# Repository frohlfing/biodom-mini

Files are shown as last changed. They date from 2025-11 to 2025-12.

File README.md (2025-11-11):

# Projekt "Biodom Mini" – Ein Hightech-Gewächshaus

Das Ziel ist ein Mini-Gewächshaus für anspruchsvolle Pflanzen, das automatisch für ein tropisches Klima sorgt.

**Features:**

- Künstliche Sonne
- Konstante Temperatur
- Konstante Luftfeuchtigkeit
- Automatische Bewässerung
- Kamera (schießt regelmäßig Bilder für Zeitraffer-Video)
- Display (zeigt aktuelle Werte an)
- Webinterface (über WLAN erreichbar)

## Projektdokumentation

Eine detailliertere technische Dokumentation befindet sich in [Projektdokumentation.md](docs/Projektdokumentation.md).

## Lizenz

Dieses Projekt steht unter der [GPL-3.0-Lizenz](LICENSE).

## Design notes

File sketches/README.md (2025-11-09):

# Beschreibung Arduino Sketches 

In diesem Verzeichnis liegen Sketche für die [Arduino IDE](https://www.arduino.cc/en/software/), die ich für den ersten Funktionstest der Bauteile verwendet habe.

Im Unterordner `JpgToBmp` liegen die Sketche, die ich für die Entwicklung der gleichnamigen Funktion verwendet habe.

## 📦 Installation

Folgende Bibliotheken werden für diese Sketche benötigt und müssen mittels Library Manager installiert werden:

* [Arducam_mini 1.0.1 by Arducam](https://github.com/ArduCAM/Arducam_mini) für die ArduCAM Mini 2MP Plus (mit OV2640-Chip)
* [BH1750 1.3.0 by claws (Christofer Laws)](https://github.com/claws/BH1750) für den Lichtsensor GY-302 (BH1750)
* [DallasTemperature 4.0.5 by Miles Burton](https://github.com/milesburton/Arduino-Temperature-Control-Library) für den Bodentemperatursensor DS18B20
* [OneWire 2.3.8 by Paul Stoffregen](https://github.com/PaulStoffregen/OneWire) für den Bodentemperatursensor DS18B20 (setzt DallasTemperature voraus)
* [SimpleDHT 1.0.15 by Winlin](https://github.com/winlinvip/SimpleDHT) für den Raumtemperatur- und Luftfeuchtigkeitssensor AM2302
* [U8g2 2.35.30 by oliver](https://github.com/olikraus/u8g2) für das 1.3 Zoll OLED Display SSH1106
* [TJpg_Decoder 1.1.0 by Bodmer](https://github.com/Bodmer/TJpg_Decoder) für den JPGtoXBM-Konverter

(TODO: Diese nicht: [JPEGDEC 1.8.4 by Larry Bank](https://github.com/bitbank2/JPEGDEC) für den JPGtoXBM-Konverter)

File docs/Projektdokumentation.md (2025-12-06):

# Projekt "Biodom Mini" – Ein Hightech-Gewächshaus

* **Version:** 1.0.2
* **Datum:** 11.11.2025
* **Autor:** Frank Rohlfing

Das Ziel ist ein Mini-Gewächshaus für anspruchsvolle Pflanzen, das automatisch für ein tropisches Klima sorgt.

**Features:**

- Künstliche Sonne
- Konstante Temperatur
- Konstante Luftfeuchtigkeit
- Automatische Bewässerung
- Kamera (schießt ein Bild pro Tag für Zeitraffer-Video)
- Display (zeigt aktuelle Werte an)
- Webinterface (über WLAN erreichbar)

**Inhaltsverzeichnis**

* [Projekt "Biodom Mini" – Ein Hightech-Gewächshaus](#projekt-biodom-mini--ein-hightech-gewächshaus)
  * [1. Gehäuse](#1-gehäuse)
  * [2. Steuereinheit](#2-steuereinheit)
  * [3. Sensoren](#3-sensoren)
  * [4. Aktoren](#4-aktoren)
  * [5. Sonstige Peripheriegeräte](#5-sonstige-peripheriegeräte)
  * [6. Stromversorgung](#6-stromversorgung)
  * [7. Schaltplan](#7-schaltplan)
  * [8. Programmierung](#8-programmierung)

  * [Anhang](#anhang)

## 1. Gehäuse

### Gewächshaus 

AKERBÄR Gewächshaus 65, anthrazit

[Ikea](https://www.ikea.com/de/de/p/akerbaer-gewaechshaus-drinnen-draussen-anthrazit-20537175/)
29,99 €

Gewächshaus

Maße Gewächshaus

Maße: 65 x 22 (bzw. 13 oben) x 40 cm (B, T, H) 

### Blumenkasten 

Geli Blumenkasten Standard 60 cm

[Obi](https://www.obi.de/p/7331374/geli-blumenkasten-standard-ca-60-cm-anthrazit)
1,65 €

Blumenkasten

Maße: 60 x 18 x 13,7 cm (B, T, H)	

### Behälter für den Teich

Bedingungen: 
* Der Behälter muss eine grade Wand haben, um den Füllstandsensor anbringen zu können.
* Das Material darf aufgrund des Füllstandsensors nicht aus Metall sein (Glas, Kunststoff oder Keramik ist ok).
* Muss in den Blumenkasten passen (max. 12 cm tief, 13 cm hoch).

Ich habe diese Vase im Keller gefunden, passt perfekt:

* Material: Glas
* Außenmaße: 10 x 10 x 10 cm  
* Wandstärke: 4mm

### Bewässerungsset

Bewässerungsschlauch 4/6 mm (passend zur Wasserpumpe)

Bewässerungsset
Bewässerungsset

[Amazon](https://www.amazon.de/gp/product/B0DSP1KB8S)
7,98 €; "Einzelpreis": 3,99 €		

5 m Schlauch, 10 Tropf-Sprinkler, 2 Ventile, Verbinder (reicht locker für 2 Häuschen)

### Elektronik-Box

Kunststoffgehäuse 200 x 120 x 75 mm

Kunststoffgehäuse

[Amazon](https://www.amazon.de/dp/B0DJD3WC1V)
7,99 €

* IP65 (wasserdicht)

In das Gehäuse wird das Mainboard geschraubt. 

### Mainboard

Lochrasterplatine, 160 x 100 mm, blau 

Standard-Platine

[Amazon](https://www.amazon.de/gp/product/B081K7467B)
7,99 €

* Durchkontaktiert, runde Pads
* Rastermaß: 2,54 mm
* 1,6 mm dick

### Klinkenstecker und -Buchsen für die Sensoren (Kamera ausgenommen)

3.5 mm Stereo-Klinkenstecker und -Buchse 

Klinkenstecker und -Buchse

https://www.amazon.de/dp/B09TK2HNKD
6,79 € (10 Stück)

* Muss Stereo sein (3 Pins)!

4 Klinkenbuchsen werden benötigt für:
* Luft
* Bodentemperatur
* Bodenfeuchte
* Wasserstand

**Pinbelegung:**!



### Hohlstecker und -Buchen für die Aktoren und Stromversorgung

DC Power Jack Buchse und Stecker, 2.1 mm, 2 Polig 

Auch DC-Stecker und DC-Buchse genannt.

DC Buchse

[Amazon](https://www.amazon.de/dp/B07QNWSKN2)
7,49 € (12 Stück)

* Typ: 5.5 x 2.1 mm Buchse (passend zum 5.5x2.1 mm Holstecker des Netzteils)

7 Hohlstecker-Buchsen werden benötigt für:
* Lampe 1
* Lampe 2
* Heizer
* Dunst
* Pumpe
* Lüfter
* DC 12V

**Pinbelegung:**!



### Sonstiges Zubehör

**Stiftleisten und Buchsenleisten zum Einlöten auf die Platine** 

Auch unter "Pinheader" zu finden.

  Stift- und Buchenleisten

  [Amazon](https://www.amazon.de/dp/B0BZH6YZF8)
  10,99 €

**Kabelschlauch, selbstschließend**

Kabelschlauch

6 mm Durchmesser, 3 m: 
[Amazon](https://www.amazon.de/dp/B07FW5H57B)
7,99 €

13 mm Durchmesser, 3 m: 
[Amazon](https://www.amazon.de/dp/B07FW3GTXB)
7,99 €

**Abstandhalter Set**

Abstandhalter

[Amazon](https://www.amazon.de/dp/B0DCS5C7SN)
8,99 €

**Schraubklemmen Set**
Schraubklemmen
[Amazon](https://www.amazon.de/dp/B082ZNRQMJ)
8,99 €

## 2. Steuereinheit

### Mikrocontroller

ESP32-DevKitC V2

ESP32-DevKitC V2

[Amazon](https://www.amazon.de/dp/B074RGW2VQ)
10,99 €

[AZ-Delivery e-Book](https://cdn.shopify.com/s/files/1/1509/1638/files/AZ281_A_18-10_DE_B08BTWJGFX_e699c448-ffc6-4744-8b93-5c9f102d22b0.pdf),  
[Espressif Doku](https://docs.platformio.org/en/latest/boards/espressif32/esp32-c3-devkitc-02.html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),  
[Datasheet](https://cdn.shopify.com/s/files/1/1509/1638/files/ESP_-_32_NodeMCU_Developmentboard_Datenblatt_AZ-Delivery_Vertriebs_GmbH_10f68f6c-a9bb-49c6-a825-07979441739f.pdf)

* Micro-USB-Anschluss
* 38-Pin
* ESP32-WROOM-32-Chip
* CP2102

**Anmerkung:**

Das Modell mit UCD-C macht nur Probleme. Keins meiner UCB-C-Kabel hat funktioniert.

**Pinbelegung:**
<pre>  
                                       ┌────────────────┐
                           +3.3V Out ──┤ 3V3 ESP32  GND ├── GND
                                     ──┤ EN  DevKit G23 ├── GPIO23 SPI_MOSI ──► Kamera + SD-Karte
  Reserve analog./dgl. In ──► GPIO36 ──┤ SP  C V2   G22 ├── GPIO22 I2C_SCL  ──► Kamera + Display + Lichtstärke
       (frei analog./dgl. In) GPIO39 ──┤ SN         TXD ├── GPIO1  (UART0_TX)
    Bodenfeuchte (analog) ──► GPIO34 ──┤ G34        RXD ├── GPIO3  (UART0_RX)
              Wasserstand ──► GPIO35 ──┤ G35        G21 ├── GPIO21 I2C_SDA  ◄─► Kamera + Display + Lichtstärke
         Dunst Relais IN7 ◄── GPIO32 ──┤ G32        GND ├── GND
         Pumpe Relais IN6 ◄── GPIO33 ──┤ G33        G19 ├── GPIO19 SPI_MISO ◄── Kamera + SD-Karte
        Lüfter Relais IN5 ◄── GPIO25 ──┤ G25        G18 ├── GPIO18 SPI_CLK  ──► Kamera + SD-Karte
        Heizer Relais IN4 ◄── GPIO26 ──┤ G26         G5 ├── ──► LED
       Lampe-2 Relais IN3 ◄── GPIO27 ──┤ G27        G17 ├── GPIO17 SPI_CS   ──► Kamera
       Lampe-1 Relais IN2 ◄── GPIO14 ──┤ G14        G16 ├── GPIO16 SPI_CS   ──► SD-Karte
                        (frei, Boot) ──┤ G12         G4 ├── GPIO4           ◄─► Bodentemperatur (One-Wire)
                                 GND ──┤ GND         G0 ├── (frei, Boot)
  Luft (One-Wire-ähnlich) ◄─► GPIO13 ──┤ G13         G2 ├── (frei, Boot)
                                     ──┤ SD2        G15 ├── (frei, Boot)
                                     ──┤ SD3        SD1 ├──
                                     ──┤ CMD        SD0 ├──
                              +5V in ──┤ 5V  [USB]  CLK ├──
                                       └────────────────┘
</pre>

### Relaismodul

8-Kanal Relaismodul mit Optokoppler, 5V

[Amazon](https://www.amazon.de/dp/B07CT7SLYQ)
9,59 €

<pre>
         ┌────────────────┐
         │ 8 Relay    NC1 ├──  
         │ Module    Com1 ├──
         │            NO1 ├──
         │            NC2 ├──
         │           Com2 ├── +12V        GND ─O──(schwarz)── GND
         │            NO2 ├────────────────────O──(rot)────── A1: Lampe 1
   GND ──┤ GND        NC3 ├──   
       ─►┤ IN1       Com3 ├── +12V        GND ─O──(schwarz)── GND
GPIO14 ─►┤ IN2        NO3 ├────────────────────O──(rot)────── A2: Lampe 2
GPIO27 ─►┤ IN3        NC4 ├──
GPIO26 ─►┤ IN4       Com4 ├── +12V        GND ─O──(schwarz)── GND
GPIO25 ─►┤ IN5        NO4 ├────────────────────O──(rot)────── A3: Heizer
GPIO33 ─►┤ IN6        NC5 ├──
GPIO32 ──┤ IN7       Com5 ├── +12V        GND ─O──(schwarz)── GND
       ──┤ IN8        NO5 ├────────────────────O──(rot)────── A4: Lüfter
   +5V ──┤ VCC        NC6 ├──
         │           Com6 ├── +12V         GND ─O──(schwarz)── GND
         │            NO6 ├────────────────────O──(rot)────── A5: Pumpe  
         │            NC7 ├──
         │           Com7 ├── +5V        GND ─O──(schwarz)── GND
       ──┤ GND        NO7 ├────────────────────O──(rot)────── A6: Dunst
   Jum- ┌┤ VCC        NC8 ├──  
   per  └┤ JD-VCC    Com8 ├──
         │            NO8 ├──
         └────────────────┘
</pre>

**Anmerkung:**

Der Jumper zwischen VCC und JD-VCC muss gesteckt sein, da die Relais-Spulen auch von Steuerstromkreis versorgt werden sollen.

Um Induktionsspitzen beim Schalten abzufangen, wird ein Stützkondensator beim Spannungswandler eingesetzt (s. Kapitel6).

## 3. Sensoren

| Präfix | Name | Spezifikation | GPIO | Einkauf |
|---|---|---|---|---|
| S1 | Raumtemperatur- und Luftfeuchtigkeitssensor | AM2302 Module | GPIO13 | [Amazon](https://www.amazon.de/dp/B078SVZB1X) 8,49 € |
| S2 | Bodentemperatursensor | DS18B20 | GPIO4  | [Amazon](https://www.amazon.de/dp/B01MZG48OE) 8,29 € (2 Stück); Einzelpreis: 4,15 € |
| S3 | Bodenfeuchtigkeitssensor | Capacitive Soil Sensor v1.2 | GPIO34 | [Amazon](https://www.amazon.de/dp/B07HJ6N1S4) 6,46 € |
| S4 | Füllstandsensor | XKC-Y25-NPN | GPIO35 | [Amazon](https://www.amazon.de/dp/B0C1ZVZF2L) 10,19 € |
| S5 | Lichtsensor | GY-302 BH1750 | (I2C)  | [Amazon](https://www.amazon.de/dp/B07TKWNGZ4) 5,49 € |

### S1: AM2302
<pre>
┌────────────────┐
│ AM2302       - ├──(schwarz)─O─── GND 
│ Module     Out ├─►───(gelb)─O──► GPIO13
│              + ├──────(rot)─O─── +3.3V
└────────────────┘             
</pre>

### S2: DS18B20
<pre>
┌────────────────┐                   R1=4.7k
│ DS18B20    GND ├──(schwarz)─O────────────────── GND 
│           DATA ├─►───(gelb)─O─────┬───────────► GPIO4
│            VCC ├──────(rot)─O──┐  └─[ R1 ]─┐
└────────────────┘               └───────────┴─── +3.3V
</pre>

Pull-Up-Widerstand R1 = 4.7 kΩ

### S3: Capacitive Soil Sensor v1.2
<pre>
┌─────────────────┐
│ Capacitive  GND ├──(schwarz)─O─── GND 
│ Hygrometer  VCC ├──────(rot)─O─── +5V
│ v1.2       AOUT ├─►───(gelb)─O─►─ GPIO34
└─────────────────┘
</pre>

### S4: XKC-Y25-NPN

| Pin | Bezeichnung | Farbe am Sensor | Farbe am Klinkenstecker | Beschreibung |
|-----|---|---|---|---|
| 1 | VCC | braun | rot | Versorgung (5–12V) |  
| 2 | OUT | gelb | grün | Digitaler Ausgang | 
| 3 | GND | blau | weiß | GND |
| 4 | MODE | schwarz | - | Modus-Umschaltung (wird nicht benötigt)  | 

Eventuell sind Schwarz und Gelb vertauscht (OUT = Schwarz, MODE = Gelb)

<pre>
┌────────────────┐                     R2=10k 
│ XKC-Y25    VCC ├────(braun)─O───────────────── +5V   
│ -NPN       OUT ├─►───(gelb)─O─────┬──[ R2 ]─── +3.3V 
│            GND ├─────(blau)─O───┐ └─────────►─ GPIO35    
│           MODE ├──(schwarz)─O   └───────────── GND         
└────────────────┘    
</pre>

Pull-Up-Widerstand R2 = 10 kΩ

#### S5: BH1750
<pre>
┌────────────────┐
│ GY-302     VDD ├──────(rot)─O── +3.3V
│ BH1750     GND ├──(schwarz)─O── GND
│            SCL ├────(braun)─O─◄─ GPIO22
│            SDA ├───(orange)─O◄─► GPIO21 
│           ADDR ├─────(gelb)─O──
└────────────────┘
</pre>

## 4. Aktoren

| Präfix | Name | GPIO |
|---|---|---|
| A1 | Lampe 1 | GPIO14 | 
| A2 | Lampe 2 | GPIO27 |
| A3 | Heizer | GPIO26 |
| A4 | Lüfter | GPIO25 |
| A5 | Pumpe | GPIO33 |
| A6 | Vernebler | GPIO32 |

### A1, A2: Lampe

LED Grow Light 12V/60W, Vollspektrum, 4:1, IP65

LED-Streifen

[Amazon](https://www.amazon.de/gp/product/B076D3GCH4)
18,99 €

* 12V, 60W
* Rot:Blau = 4:1
* Vollspektrum
* IP65 (wasserdicht)
* 5m-Streifen (1 cm breit) mit 300 LEDs (SMD 5050)
* Hersteller: Tesfish

12V/60W = 5A (lt. Hersteller) -> Damit ist das Limit für ein Relais des Relais-Moduls erreicht. Daher teile ich den 
5m-Streifen in zwei Hälften, um die Last auf zwei Relais verteilen zu können. 
Außerdem könnte ich das Licht so in zwei Helligkeitsstufen schalten.  

**Aufteilung des LED-Streifens in 2 Lampen:**
<pre>
            O─▓▓▓▓▓▓▓▓▓▓▓▓▓▓▓▓▓▓▓▓▓▓▓▓▓▓▓▓▓▓▓─O┐
          ┌─O─░░░░░░░░░░░░░░░░░░░░░░░░░░░░░░░─O│┐
          │┌O─▓▓▓▓▓▓▓▓▓▓▓▓▓▓▓▓▓▓▓▓▓▓▓▓▓▓▓▓▓▓▓─O┘│
Lampe 1 O─┼─O─░░░░░░░░░░░░░░░  ░░░░░░░░░░░░░░─O─┘
Lampe 2 O─│┼O─▓▓▓▓▓▓▓▓▓▓▓▓▓▓▓  ▓▓▓▓▓▓▓▓▓▓▓▓▓▓─O┐
          └─O─░░░░░░░░░░░░░░░░░░░░░░░░░░░░░░░─O│┐
           └O─▓▓▓▓▓▓▓▓▓▓▓▓▓▓▓▓▓▓▓▓▓▓▓▓▓▓▓▓▓▓▓─O┘│
            O─░░░░░░░░░░░░░░░░░░░░░░░░░░░░░░░─O─┘
            <-------------- 60cm ------------->
</pre>

**UPDATE: Tatsächliche Leistung (Messwerte):**

* Leistung pro Streifenhälfte (2,5m): Spannung: 12 V, Strom: 2 A -> Reale Leistung: P = U * I = 12 V * 2 A = 24 Watt
* Leistung des gesamten Streifens (2 x 2,5m): Spannung: 11.9 V, Strom: 3.8 A -> Reale Gesamtleistung: P = 11.9 V * 3.8 A ≈ 45 Watt

Der gemessene Strom ist unter 4A, es würde 1 Relais reichen. (Sicherheitsmarge von 20 % ist ok). 
Aber dann kann ich nicht mehr zwei Helligkeitsstufen schalten. 

**Pinbelegung:**
<pre>
┌────────────────┐
│ LED Grow  +12V ├──────(rot)─O── Relais IN2
│ Light 1        │
│ 30W        GND ├──(schwarz)─O── GND
└────────────────┘
┌────────────────┐
│ LED Grow  +12V ├──────(rot)─O── Relais IN3
│ Light 2        │
│ 30W        GND ├──(schwarz)─O── GND
└────────────────┘
</pre>

**Passt die Lampe zum Gehäuse?**

**Ideale Lichtmenge (PPFD):**

* Die Lichtmenge wird in der Pflanzenwissenschaft in PPFD (Photosynthetic Photon Flux Density) gemessen. 
* Die Einheit ist µmol/m²/s. Der Wert gibt an, wie viele Photonen pro Sekunde auf einen Quadratmeter treffen. 
* Typische PPFD-Werte:
	* Cannabis:
		* Keimlinge/Stecklinge: 150 - 300 µmol/m²/s
		* Vegetatives Wachstum: 300 - 600 µmol/m²/s
		* Blütephase: 600 - 1.000 µmol/m²/s
	* Zitrone, Mango, Avocado: 
		* Wachstum (Jungpflanze): 300 - 500 µmol/m²/s
		* Fruchtbildung: > 700 µmol/m²/s.
	* Allround-Gewächshaus:
		* ≈ 400-600 µmol/m²/s

**Die Lichtmenge der Lampe:**

* **Leistung der Lampe:** Die Lampe wird mit 60W beworben. Laut [Kundenrezension](https://www.amazon.de/gp/customer-reviews/RP3TF4WHOI91K/ref=cm_cr_dp_d_rvw_ttl?ie=UTF8) leistet die Lampe nur 40 W. 

* **Effizienz der Lampe:** Die Effizienz einer Lampe wird in µmol/Joule angegeben. Sie sagt aus, wie viele Licht-Photonen (µmol) pro Wattsekunde (Joule) erzeugt werden.
Typische Werte für SMD 5050 Grow-LEDs, aus denen die Lampe besteht, liegen bei 1,5 bis 1,8 µmol/Joule. 

* **Pflanzenfläche:** Das AKERBÄR Gewächshaus hat unten eine Fläche von 0,60 x 0,2 m = 0,12 m².

* Jetzt können wir rechnen:

	* Gesamter Photonenfluss (PPF): Wie viele Photonen produziert die 40W-Lampe insgesamt pro Sekunde?
  
		PPF (µmol/s) = Leistung (Watt) * Effizienz (µmol/J)
	
		* Min: 40 W * 1.5 µmol/J = 60 µmol/s
		* Max: 40 W * 1.8 µmol/J = 72 µmol/s		

	* PPFD auf der Fläche - Jetzt verteilen wir diese Gesamtmenge an Photonen auf unsere Anbaufläche.
  
		PPFD (µmol/m²/s) = PPF (µmol/s) / Fläche (m²)

		* Min: 60 µmol/s / 0,12 m² = 500 µmol/m²/s
		* Max: 72 µmol/s / 0,12 m² = 600 µmol/m²/s

=> Die Lampe passt perfekt zum Gehäuse!

### A3: Heizer

Silikon-Heizmatte, 12V/12W, 60°C

Heizmatte

[Amazon](https://www.amazon.de/dp/B09VB1Q2G4)
7,19 €

* 12V, 12W
* bis 60°C
* 10 x 12 x 1,5cm

Der tatsächliche Strombedarf beträgt 930 mA (gemessen).

**Pinbelegung:**
<pre>
┌────────────────┐
│ Heating   +12V ├─────O── Relais IN4 
│ max. 60°C      │
│ 12W        GND ├─────O── GND
└────────────────┘
</pre>

### A4: Lüfter

PC-Lüfter, Silent, 12V, 8.5 CFM, 50 mm

Super Silent Fan

[Amazon](https://www.amazon.de/dp/B01HTN8XZE)
6,94 €;

* 12 V, 50 mA
* 50 x 50 mm
* 8,5 CFM
* 17,5 dB
* 3500 Umdrehungen pro Minute
 
**Pinout:**

| Pin | Bezeichnung | Farbe | Beschreibung |
|-----|---|---|---|
| 1 | +12V | rot | Versorgung |  
| 2 | GND | schwarz | GND |  
| 3 | RPM | gelb | Tachosignal  | 

**Anmerkung:**

Das gelbe Kabel mit der Bezeichnung "RPM" (Revolutions Per Minute) wird nicht benötigt. 
Es liefert ein "Tachosignal" (typischerweise 2 Pulse pro Umdrehung). Man könnte damit z.B. per Mikrocontroller prüfen, ob der Lüfter läuft oder blockiert ist.

**Pinbelegung:**
<pre>
┌────────────────┐
│ Fan       +12V ├──────(rot)─O── Relais IN5 
│                │
│ 0.6W       GND ├──(schwarz)─O── GND
└────────────────┘
</pre>

**Montage des Lüfters:**

[Montageanleitung des PC-Lüfters](https://m.media-amazon.com/images/I/91Py5fJkHrL.pdf)

Pflanzen verbrauchen CO₂ und geben Sauerstoff ab. Die "verbrauchte" und feuchte Luft steigt auf und sammelt sich im oberen Bereich des Gewächshauses.
Die Luft muss also von unten nach oben zirkulieren. 

Der Lüfter wird die Luft nach außen pusten und muss daher oben angebracht werden.

**Reicht die Leistung des Lüfters aus?**

Wie schnell der gewählte Lüfter die gesamte Luft im Gewächshaus austauschen kann. 
Ein guter Wert für ein kleines Gewächshaus liegt bei einer Luftaustauschrate von mindestens 1-mal pro Minute.

* Der Luftstrom der Lüfter wird in CFM (Cubic Feet per Minute) angegeben: 1 CFM ≈ 0,0283 m³/min

* Der ausgewählte PC-Lüfter pustet 8,5 CFM = 8.5 * 0,0283 m³/min = 0,24055 m³/min

* Das AKERBÄR Gewächshaus hat ein Volumen von 0,65 m * (0,22 m + 0,13 m)/2 * 0,40 m = 0,0455 m³.

* Die Luftaustauschrate ist somit 0,24055 m³/min / 0,0455 m³ ≈ **5,3-mal pro Minute**

=> Der Lüfter reicht völlig aus.

### A5: Pumpe

Mini 370 Membranpumpe, 12V

Wasserpumpe
Wasserpumpe

[Amazon](https://www.amazon.de/dp/B0DX5PVTBQ)
8,98 €

Wird mit 1 m Schlauch geliefert (5 mm innen).

* max. 300mA
* Saughöhe: 2m
* Durchflussmenge: 700ml

**Pinbelegung:**
<pre>
┌────────────────┐
│ Mini      +12V ├──────(rot)─O── Relais IN6 
│ Pump           │
│ 3.6W       GND ├──(schwarz)─O── GND
└────────────────┘
</pre>

### A6: Dunst

Ultraschall-Vernebler, 5V/5W

Vernebler
Vernebler Maße

[Amazon](https://www.amazon.de/gp/product/B0FM2FZD4Z)
12,49 €		

* 5V, 5W
* 1,4m Kabel
* 4,7 x 2,5 cm (B, H)
* Wassermangelschutz
* LED Farbwechsel

USB-Stecker abknipsen und Klinkenstecker anlöten.
Kabeladern:
* Braune = VCC
* Weiß = GND

**Pinbelegung:**
<pre>
┌────────────────┐
│ Mist       +5V ├──────(rot)─O── Relais IN7 
│ Maker       D- ├─────(weiß)─O── 
│ 5W          D+ ├─────(grün)─O── 
│            GND ├──(schwarz)─O── GND
└────────────────┘
</pre>

## 5. Sonstige Peripheriegeräte

| Präfix | Name | Spezifikation | GPIO | Einkauf |
|---|---|---|---|---|
| Z1 | Display | 1.3 Zoll OLED Display, SSH1106 | (I2C) | [Amazon](https://www.amazon.de/dp/B078J78R45) 8,49 € |
| Z2 | SD-Kartenleser | MicroSD SPI Kartenleser | CS: GPIO16 | [Amazon](https://www.amazon.de/gp/product/B0DQZFBCST) 4,29 € (3 Stück); Einzelpreis: 1,43 € |
| Z3 | Kamera | ArduCAM OV2640 Mini 2MP Plus | CS: GPIO17 | [BotLand](https://botland.de/kameras-fur-arduino-und-raspberry-pi/6556-arducam-mini-ov2640-2mpx-1600x1200px-60fps-spi-kameramodul-fur-arduino--5904422358242.html) 28,86 € |
| Z4 | LED | LED 3mm, rot | GPIO5 | |

### Z1: Display

<pre>
┌────────────────┐
│ 1.3″       VDD ├──────(rot)─O── +3.3V
│ OLED       GND ├──(schwarz)─O── GND
│ Display    SCK ├────(braun)─O─◄─ GPIO22
│ SSH1106    SDA ├───(orange)─O◄─► GPIO21 
└────────────────┘
</pre>

### Z2: SD-Kartenleser

<pre>
┌────────────────┐
│ MicroSD    GND ├───O─── GND
│ SPI       MISO ├───O─►─ GPIO19
│ Module     CLK ├───O─◄─ GPIO18
│           MOSI ├───O─◄─ GPIO23 
│             CS ├───O─◄─ GPIO16 
│            3v3 ├───O─── +3.3V
└────────────────┘
 </pre>

**Speicherkarte:**

SanDisk Ultra 32 GB microSDHC, Class 10, U1

Speicherkarte

[Amazon](https://www.amazon.de/dp/B08HVWJM8C)
7,78 €

* MicroSD (bis 2 GB) und MicroSDHC (4 bis 32 GB) funktionieren mit SPI.
* Geschwindigkeitsklasse: C10 ist Standard für Arduino/ESP32-Projekte (Schreibgeschwindigkeit: mind. 10 MB/s)
* Bus-Typ: UHS-I (U1 oder U3)
* Hersteller: SanDisk (Kingston oder Transcend wäre auch ok)

Die Karte sollte FAT32-formatiert sein.

**4 GB SD-Karte Class 4. vs. 32 GB HC Class 10**

Ich habe noch eine alte 4 GB SD-Karte Class 4. Wie lang reicht die Karte, wenn pro Stunde ein Bild geschossen wird? 
Wie schnell ist sie in der Praxis?

* 93 % einer SD-Karte sind durchschnittlich praktisch nutzbar.
* Die höchste Auflösung der ArduCAM-Kamera ist 1600 x 1200 Pixel. Die Bilder werden im JPEG-Format gespeichert. 
  Ich schätze 600 KB / Bild durchschnittlich.  

Es folgt:
* 4 GB: 4 GB * 0,93 * 1024 * 1024 / 600 KB = ≈ 6500 Bilder => 6500 / 24 ≈ **270 Tage**
* 32 GB: 32 GB * 0,93 * 1024 * 1024 / 600 KB = ≈ 52000 Bilder => 52000 / 24 / 365 ≈ **6 Jahre**

Theoretische Schreibgeschwindigkeit pro Bild:
* Class 4 (min. 4 MB/s): 0.6 MB / 4 MB/s = 150 ms. 
* Class 10 (min. 14 MB/s): 0.6 MB / 10 MB/s = 60 ms.

In der Realität ist der Prozess durch den ESP32 und die SPI-Kommunikation limitiert. 
Der gesamte Vorgang (Auslesen von der Kamera + Schreiben auf die Karte) wird vermutlich eher bei 1 bis 1,5 Sekunden liegen.

### Z3: Kamera

<pre>
┌────────────────┐
│ ArduCAM    SCL ├─◄───(orange)─O─── GPIO22
│ OV2640     SDA ├◄─►────(gelb)─O─── GPIO21
│ Mini       VCC ├───────(grün)─O─── +3.3V
│ 2MP Plus   GND ├───────(blau)─O─── GND
│            SCK ├─◄─────(lila)─O─── GPIO18
│           MISO ├─►─────(grau)─O─── GPIO19
│           MOSI ├─◄─────(weiß)─O─►─ GPIO23
│             CS ├─◄──(schwarz)─O─── GPIO17 
└────────────────┘        
 </pre>

### Z4: LED

Leuchtdiode 3mm, rot 

Nützlich zum Debuggen

Das längere Beinchen ist der Pluspol.

**Pinbelegung mit Vorwiderstand:**

<pre>
                      ↗↗     
GPIO5 ─▶───[ R2 ]─────▶├───── GND
            330 Ω    LED1
</pre>

## 6. Stromversorgung

| Präfix | Name | Spezifikation | Einkauf |
|---|---|---|---|
| P1 | Spannungswandler 12V zu 5V | Step-Down-Module XL4015 | [Amazon](https://www.amazon.de/dp/B07VQCXDTC) 9,99 € (3 Stück); Einzelpreis:	3,33 € |
| P2 | 12V Netzteil, 120W | 12V Steckernetzteil Adapter, 120W | [Amazon](https://www.amazon.de/gp/product/B0DBL4FV6C) 11,99 € 9,99 € (3 Stück); Einzelpreis:	3,33 € |

### P1: Spannungswandler 12V zu 5V

**Pinbelegung:**
<pre>
                   ┌────────────────┐
Netzteil DC +12V ──┤ IN+       OUT+ ├──┬──────────────────── ESP32 +5V
                   │  XL4015 Module │  └─⁺▌|─┐ C1: 470µF
             GND ──┤ IN.       OUT- ├────────┴────────────── GND
                   └────────────────┘
</pre>

**Stützkondensator C1**:

C1: Elko 470µF, 16V

Generell ist ein Stützkondensator zu empfehlen, dieser schützt vor Spannungseinbrüchen. 
Erst recht, wenn ein Relais eingesetzt wird, dessen JD-VCC-Jumper gesteckt ist.

Wird so nah wie möglich am Ausgang des Spannungswandlers gelötet.
Das längere Beinchen und der Pin ohne Markierung auf dem Gehäuse ist PLUS (+).
 
**Anmerkung:**

Die Ausgangsspannung muss auf **5 Volt** eingestellt werden!

### Netzteil

12V Steckernetzteil Adapter, 120W

**Benötigte Leistung / max. Stromaufnahme:**

5V-Komponenten (über Spannungswandler):

* ESP32-DevKitC C: 0,2 – 0,3A (je nach WLAN-Last)
* ArduCAM (SPI): ca. 0,1A (bei Kameraaufnahme)
* SD-Kartenleser (SPI): ca. 0,05A (nur bei Zugriff)
* OLED Display: ca. 0,02A (sehr gering)
* AM2302-Modul: ca. 0,002A (vernachlässigbar)
* DS18B20: ca. 0,002A (vernachlässigbar)
* Hygrometer-Modul: ca. 0,005–0,01 A (gering)
* XKC-Y25-NPN: ca. 0,1 A (bei Aktivierung)
* Ultraschall-Vernebler: ca. 1,0 A (Hauptlast auf 5V)

=> Summe worst case: ca. 1,6 A für 5V-Komponenten

Der Spannungswandler liefert bis zu 5A, also reichlich Reserve.

12V-Komponenten:

* LED Grow Light (5m, 60W): ca. 60W → 5,0A (Hauptlast, Dauerbetrieb)
* Heizmatte (12W):	12W → 1,0A (Dauerlast)
* 2x PC-Lüfter: ca. 0,1A gesamt
* Wasserpumpe Mini: max. 0,3A (Kurzzeitbetrieb)
* Relais-Modul (8-Kanal, 6 im Gebrauch): ca. 0,3A (50mA pro Relais)	(nur wenn alle Relais gleichzeitig anziehen)

=> Summe worst case: ca. 6,7 A für 12V-Komponenten

Max. Gesamtlast am Netzteil: **ca. 8,3 A**

Das 12V-Netzteil liefert 10 A, also sind ca. 1,7 A Reserve. Das ist knapp, aber im grünen Bereich.
 
## 7. Schaltplan

Den Sachaltplan habe ich mit KiCad 9.0 erstellt.



### Leiterplatten-Entwurf



## 8. Programmierung

### Entwicklungsumgebung / Technologie-Stack

* PlatformUI mit VS Code
* ArduinoIDE (nur für den erster schneller Funktionstest und Proof Of Concepts, die Sketches liegen im Verzeichnis `sketches`)
* ESP-Prog für das Debuggen (sofern nötig)
* Webinterface via Websocket (Frontend mit HTML, CSS, Vanilla JS, Single-Page)
* OTA-Upload (Over-The-Air) für das Produktivsystem

Mit der PlatformUI wird für jedes Bauteil eine lokale Bibliothek bereitgestellt und ausführlich dokumentiert.

Es wird auch jeweils eine Bibliothek für das Webinterface, für OTA und für den Zugriff auf die Sollwerte (als persistentes Dictionary o.ä.) bereitgestellt (um `main.cpp` möglichst schlank halten zu können). 

### Steuerungslogik

Die Steuerung soll dafür sorgen, dass ein gleichmäßiges Klima für die Pflanzen im Gewächshaus herrscht. 

Es wird folgende Steuerungslogik programmiert (in `main.cpp`):

*   **Lichtsteuerung (A1 und A2):**  
	* **Zur Tageszeit** werden die Lampen eingeschaltet, wenn das natürliche Tageslicht nicht ausreicht. 
	Dazu misst der Lichtsensor (S5) kontinuierlich das Tageslicht. 
	Ist das Tageslicht dunkler als der Schwellwert `LIGHT_LUX_THRESHOLD_DARK`, wird die Lampe eingeschaltet.
	Ist das Tageslicht heller als der Schwellwert `LIGHT_LUX_THRESHOLD_BRIGHT`, wird die Lampe ausgeschaltet.
    * **Außerhalb der Tageszeit** bleiben die Lampen aus.
    * Die Tageszeit ist definiert durch Einschaltzeit `LIGHT_ON_HOUR` und Ausschaltzeit `LIGHT_OFF_HOUR`.
    * Lampe 1 und Lampe 2 werden unabhängig voneinander gesteuert, d.h., für die Lampen können unterschiedliche Tageszeiten und Schwellwerte haben. 
  
* **Heizungssteuerung (A3):**  
Die Heizmatte wird aktiviert, wenn die **Bodentemperatur (S2)** unter den Zielwert `SOIL_TEMPERATUR_TARGET` fällt. Um ein ständiges An- und Ausschalten (Flattern) zu verhindern, wird eine Hysterese implementiert: Die Heizung schaltet sich erst wieder aus, wenn die Temperatur den Zielwert um 0.5 °C überschreitet.

*   **Lüftersteuerung (A4):**
Der Lüfter wird aktiviert, wenn die **Raumtemperatur (S1)** den Schwellwert `AIR_TEMPERATUR_THRESHOLD_HIGH` überschreitet. Er läuft dann für eine feste Dauer von `FAN_COOLDOWN_DURATION_MS`, um die warme und feuchte Luft effektiv abzuführen, und schaltet sich danach automatisch ab. Dies verhindert eine zu schnelle Austrocknung durch Dauerbetrieb.

*   **Bewässerungssteuerung (A5):** 
Die Wasserpumpe wird aktiviert, wenn die **Bodenfeuchte (S3)** unter den Zielwert `SOIL_MOISTURE_TARGET` fällt. Die Pumpe läuft dann für eine feste Dauer von `WATERING_DURATION_MS`, um eine definierte Menge Wasser abzugeben.  
**Ausnahme:** Die Pumpe wird niemals aktiviert, wenn der **Wasserstandsensor (S4)** meldet, dass der Wasserbehälter leer ist, um ein Trockenlaufen zu verhindern.

*   **Luftfeuchtesteuerung (A6):** Der Ultraschall-Vernebler (Dunst) wird eingeschaltet, wenn die **relative Luftfeuchtigkeit (S1)** unter den Zielwert `HUMIDITY_TARGET` sinkt. Auch hier sorgt eine Hysterese dafür, dass er sich erst wieder abschaltet, wenn die Luftfeuchtigkeit 5 % über dem Zielwert liegt. 
**Ausnahme:** Der Vernebler wird nur aktiviert, wenn der **Wasserstandsensor (S4)** ausreichend Wasser meldet.

*   **Wasserstands-Überwachung (S4):** Der Füllstandsensor wird kontinuierlich überwacht. Wenn er einen niedrigen Wasserstand (`!WATER_LEVEL_TRIGGERED`) meldet, wird auf dem Display eine bildschirmfüllende, blinkende Warnung angezeigt. Zusätzlich werden Pumpe (A5) und Vernebler (A6) deaktiviert.

*   **Kamerasteuerung (Z3):** In einem festen Intervall (z.B. alle 60 Minuten) wird ein Foto in hoher Auflösung (1600x1200) aufgenommen und auf der SD-Karte (Z2) gespeichert. Der Dateiname enthält einen Zeitstempel, um eine chronologische Sortierung zu ermöglichen (z.B. `img_20241017_143000.jpg`).

### Optimale Klimawerte

Eine Internet-Recherche über optimale Klimawerte für tropische Pflanzen ergab Folgendes:

*   **Temperatur:** 
    - Tropische Pflanzen, die oft aus Regenwäldern stammen, benötigen ein stabiles Klima mit hoher Luftfeuchtigkeit und gleichmäßig hohen Temperaturen. [1]

    - Für tropische Pflanzen sind Tagestemperaturen zwischen 20 °C und 30 °C ideal. [2]

    - Nachts sollten die Temperaturen nicht wesentlich unter 20 °C fallen. [3]

    - Die Bodentemperatur ist für die Wurzelaktivität ebenfalls entscheidend und sollte im warmen Bereich liegen. [2]

*   **Luftfeuchtigkeit:** 
    - Eine hohe relative Luftfeuchtigkeit ist für die meisten tropischen Pflanzen essenziell, um die Transpiration über die Blätter zu minimieren. Werte zwischen 60 % und 80 % sind optimal. [2]

*   **Bodenfeuchte:**  
    - Der Boden sollte konstant feucht, aber niemals durchnässt sein. [4]

    - Staunässe führt schnell zu Wurzelfäule und muss unbedingt vermieden werden. [5]

    - Der Boden sollte zwischen den Gießvorgängen leicht antrocknen können. [5]

*   **Lichtzyklus:** 
    - Ein Lichtzyklus von 12 bis 14 Stunden pro Tag simuliert die Bedingungen am Äquator und fördert ein gesundes vegetatives Wachstum. [6]

Quellen:

* [[1] hoklartherm.de](https://www.hoklartherm.de/ratgeber/tropische-pflanzen-gewaechshaus/)
* [[2] erlebnisgaertnerei.com](https://erlebnisgaertnerei.com/die-richtigen-temperaturen-im-gewaechshaus/)
* [[3] samen.de](https://samen.de/blog/temperaturmanagement-in-der-pflanzenanzucht-fuer-gesundes-pflanzenwachstum.html) 
* [[4] palmenstadl.de](https://palmenstadl.de/Die-richtige-Luftfeuchtigkeit-fuer-mediterrane-tropische-und-Wuestenpflanzen)  
* [[5] urban-jungle.store](https://www.urban-jungle.store/wie-giesse-ich-zimmerpflanzen-richtig/) 
* [[6] harmony-plants.com](https://www.harmony-plants.com/blogs/pflanzenmagazin/topf-und-bodenauswahl-fuer-tropische-pflanzen)

Damit lege ich folgende Sollwerte als Voreinstellung fest (diese können per Webinterface verändert werden): 

*   **`SOIL_TEMPERATUR_TARGET`**: `24.0` °C
*   **`SOIL_MOISTURE_TARGET`**: `50` % (Ein guter Mittelwert, der Staunässe vermeidet)
*   **`AIR_TEMPERATUR_THRESHOLD_HIGH`**: `28.0` °C (Ab hier wird es kritisch, Kühlung ist nötig)
*   **`HUMIDITY_TARGET`**: `70.0` %
*   **`LIGHT_ON_HOUR`**: `6` (6:00 Uhr)
*   **`LIGHT_OFF_HOUR`**: `20` (20:00 Uhr, ergibt einen 14-Stunden-Tag)

### Funktionsumfang

* **Bootvorgang:**  
  Nach dem Start wird eine Funktionsprüfung durchgeführt. Die Ergebnisse scrollen durch das Display. Wenn alles funktioniert, wird ein Splash-Screen (mein Portrait) für ein paar Sekunden angezeigt. Danach wird das Dashboard angezeigt. 

* **Dashboard:**  
  Das Dashboard teilt den Bildschirm in mehreren Bereichen auf. In jedem Bereich werden zusammenhängende Messwerte angezeigt. 

  Die Werte im Dashboard werden mit passenden Icons versehen:

  | Icon (XMB)     |                                                                | Verwendung                                                                       |
  |----------------|----------------------------------------------------------------|----------------------------------------------------------------------------------|
  | thermometer    | thermometer       | Icon für Raumtemperatur (S1)                                                     |
  | wet            | wet                       | Icon für Luftfeuchtigkeit (S1)                                                   |
  | engine_coolant | engine_coolant | Icon für Bodentemperatur (S2)                                                    |
  | moisture       | moisture             | Icon für Bodenfeuchte (S3)                                                       |
  | radiator       | radiator             | Heizung (A3) aktiviert (überlagert Icon für Bodentemperatur)                     |
  | air            | air                       | Lüfter (A4) aktiviert (überlagert Icons für Raumtemperatur und Luftfeuchtigkeit) |
  | rainy_weather  | rainy_weather   | Pumpe (A5) aktiviert (überlagert Icon für Bodenfeuchte)                          |
  | dry            | dry                       | Vernebler (A6) aktiviert (überlagert Icon für Bodenfeuchte)                      |
  
  Die ursprünglichen Icons habe ich bei [Icons8](https://icons8.com/icons/all--mono--size-small--technique-line) gefunden und in `data/icons` gespeichert (wo sie für das Webinterface verfügbar sind).  
  Diese unterliegen der [Universal Multimedia License von Icons8](https://intercom.help/icons8-7fb7577e8170/en/articles/5534926-universal-multimedia-license-agreement-for-icons8).
  Demnach dürfen sie verwendet werden, solange das Projekt nicht-kommerziell ist. 
  
  Die Icons habe ich mit GIMP in das XMB-Format konvertiert und im `Include`-Verzeichnis gespeichert, sodass sie auf dem OLED-Display angezeigt werden können.

* **Warnung bei niedrigem Wasserstand:**  
  Bevor der Wasserreservoir (Teich) trocken läuft, soll nicht das Dashboard, sondern eine blinkende Warnung auf dem Display angezeigt werden (gern mit Icon). Über das Handy soll der Benutzer auch gewarnt werden (per E-Mail?).

* **Bild aufnehmen:**  
  Nach einem festgelegten Intervall (alle x Stunden) wird ein Bild geschossen und auf der SD-Karte gespeichert. Direkt danach wird ein weiteres Bild mit niedrigster Auflösung erzeugt und auf dem Display für ein paar Sekunden angezeigt, um zu zeigen, dass ein Bild gespeichert wurde. 

* **Webinterface:**  
  Das Webinterface bietet folgende Funktionen für das Handy an:
  * Als Startseite wird das Dashboard angezeigt. 
  * Auf einer anderen Seite (bzw. Kartenreiter) können die Parameter für die Automatisierung verändert werden.
  *	Die Aktoren können manuell ein- und ausgeschaltet werden (wobei die Automatisierung dann außer Kraft gesetzt wird).
  * Außerdem gibt es eine Gallery mit den aufgenommenen Bilder und die Möglichkeit, diese als Zeitraffer-Video abzuspielen. 
  * Eine weitere Funktion zeigt Liniendiagramme mit den Messwerten.

## Anhang

### Verwendete ASCII-Schaltzeichen 

<pre>
Datenrichtung (Input, Output, Bidirektional)
◄── 
──► 
◄─►

Buchse
+ O──
- O──
            
IC, Sensor, Aktor
  ┌────────────────┐
──┤ In+       Out+ ├──
  │       U1       │
──┤ In-       Out- ├──
  └────────────────┘

Transistor   │ │ │
  ┌─────┐   ┌┴─┴─┴┐
  │ Q1  │   │C B E│
  │     │   │     │
  │C B E│   │ Q1  │   
  └┬─┬─┬┘   └─────┘
   │ │ │

Kreuzung:
─┼─

Widerstand
───[ R1 ]───

Kondensator
───┤├─── 
   C1

Elko
──⁺▌|───
+  C2  -  (das längere Beinchen ist der Pluspol)

Diode
───▶├───
+  D1  - (Ring)
   
LED
    ↗↗
───▶├───
+  LD1 -  (das längere Beinchen ist der Pluspol)
   
Fotodiode
   ↙↙
───▶├────
+  PD1  -

Lampe
───(╳)───
   HL1

</pre>

### Verwendete Präfixe im Schaltplan

* U: Mikrocontroller, ICs
* K: Relais (Kontaktor)
* S: Sensor
* A: Aktor
* Z: Sonstige Peripherie
* R: Widerstand (Resistor)
* C: Kondensator/Elko (Capacitor)
* P: Stromversorgung (Power Supply)
* Q: Transistor
* D: Diode
* H: Lampe
* J: Anschluss (Stiftleiste, Buchsenleiste, DC-Hohlbuchse,...)

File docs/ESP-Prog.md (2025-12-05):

# ESP-Prog

ESP-Prog ist ein Debugging-Tool von Espressif, basierend auf dem FT2232HL-Chip.

ESP-Prog  
[Benutzerhandbuch](https://docs.espressif.com/projects/esp-dev-kits/en/latest/other/esp-prog/user_guide.html)  
[H/W-Referenz](https://docs.espressif.com/projects/esp-dev-kits/en/latest/other/esp-prog/reference/reference-doc.html)  
[Erste Schritte mit PlatformIO](https://docs.platformio.org/en/latest/tutorials/espressif32/arduino_debugging_unit_testing.html)

## Schnittstellen

Der ESP-Prog stellt über ein einziges USB-Kabel zwei Schnittstellen bereit (per FTDI FT2232HL Chip):

* Interface 0 (JTAG-Schnittstelle): für Debugging und Upload via Standard-Debugging-Tool OpenOCD
* Interface 1 (UART-Schnittstelle): für Serielle Kommunikation (Serial Monitor/Plotter) und Upload via esptool.py

**Kommunikationswege:**

* Debug: PC -> USB -> ESP-Prog -> Interface 0 (JTAG) -> ESP32
* Serieller Monitor: ESP32 -> Interface 1 (UART) -> ESP-Prog -> USB -> PC

## Treiber

**Erforderliche Treiber unter Windows:**

* Für **Interface 0** muss der FTDI-Treiber durch einen WinUSB-Treiber ersetzt werden, 
weil OpenOCD nicht direkt mit dem FTDI-Treiber kommunizieren kann.

  Das geschieht so:

  1) [VCP-Treiber](https://ftdichip.com/drivers/vcp-drivers/) herunterladen und installieren
  VCP-Treiber
  2) Mit dem [Zadig-Tool](https://zadig.akeo.ie/) für "Dual RS232-HS (Interface 0)" den Treiber "FIDIBUS (v2.12.36.20)" mit "WinUSB (v6.1.7600.16385)" ersetzen. 
  Nachtrag: Der Upload läuft damit nicht zuverlässig. Hab nun "libusbK (v3.1.0.0)" installiert.
  Zadig
  3 ) USB-Kabel aus und wieder einstecken.

* Für **Interface 1** wird der benötigte FTDI-Treiber automatisch installiert, wenn der ESP-Prog zum ersten Mal angeschlossen wird.

Nach erfolgreicher Installation steht im Gerätemanager unter "USB-Geräte" der Eintrag "Dual RS232-HS" (für Interface 0, JTAG) und 
unter "Anschlüsse (COM & LPT)" der Eintrag "USB Serail Port (COM6)" (für Interface 1, UART).

Quelle: [BerryBase](https://blog.berrybase.de/esp32-debuggen-mit-espressif-esp-prog-platformio/)

## Buchsen

**Pinbelegung der PROG-Buchse:**

PROG-Schnittstelle

| Pin am ESP-Prog | | Farbe | Pin am ESP32 | 
|---|---|---|---|
| 1 EN | Reset | schwarz | EN | | 
| 2 VDD | VCC | rot | 3.3V oder nicht verbunden | 
| 3 TXD | UART Transmit | weiß | GPIO1 (TXD) |  
| 4 GND | GND | blau | GND |
| 5 RXD | UART Receive  | grau | GPIO3 (RXD) | 
| 6 IO0 | Strapping Pin | lila | GPIO0 | 

**Pinbelegung der JTAG-Buchse (für Debugging):**

JTAG-Schnittstelle

| Pin am ESP-Prog | | Farbe  | Pin am ESP32 | 
|---|---|---|---|
| 1 VDD | VCC | rot | 3.3V oder nicht verbunden | 
| 2 TMS | Test Mode State | braun  | GPIO14 | 
| 4 TCK | Test Clock | orange | GPIO13 |  
| 6 TDO | Test Data Out | gelb | GPIO15 | 
| 8 TDI | Test Data In | grün | GPIO12 | 
| 3,5,7,9 GND | GND | blau | GND | 

**Anschlusskabel:**

* Flachbandkabel (Ribbon Cable, meist 1.27mm oder 2.54mm Pitch)
* IDC-Stecker (2×3 und 2×5, Pfostenverbinder mit Schneidklemmen, auch Wannenstecker genannt)

Die Klemmen kann man mittels Schraubstock zusammenpressen.

## Stromversorgung

Der ESP-Prog wird über das USB-Kabel versorgt. Er kann den ESP32 mitversorgen, indem der 3.3V-Pin verbunden wird. 
Wenn aber eine andere Stromquelle für den ESP32 angeschlossen ist, **darf der 3.3V-Pin nicht verbunden werden!**

**Die PWR-SEL-Jumper müssen auf 3.3V gesetzt sein!**

Auf 5V dürfen keine der Jumper gesteckt werden, da sonst an einigen Pins mehr als 3.3 V liegen und der ESP32 darauf verschnupft reagieren könnte.

**Konfiguration:**

```
[env:esp32dev]
platform = espressif32
board = esp32dev
framework = arduino

; Debug- & Upload- Konfiguration
debug_tool = esp-prog
upload_protocol = esp-prog ; Upload über Inerface 0 (JTAG)
; upload_protocol = esptool ; Upload über Inerface 1 (UART)

; Serielle Monitor Konfiguration
monitor_port = COM6 ; siehe Gerätemanager unter "Anschlüsse (COM & LPT)" oder PlatformIO unter PIO Home -> Devices
monitor_speed = 115200

; Level 0=None, 1=Error, 2=Warn, 3=Info, 4=Debug, 5=Verbose
; siehe https://docs.platformio.org/en/latest/platforms/espressif32.html
build_flags = -DDEBUG_BAUDRATE=115200 ;-DCORE_DEBUG_LEVEL=1

; Enthält Einstellungen für den Build-Prozess während des Debuggens, wie z.B. O0 und ggdb, 
; um die Sichtbarkeit aller Variablen zu gewährleisten.
debug_build_flags = -O0 -g -ggdb

; Ermöglicht das Setzen von Breakpoints in der Setup-Funktion, was besonders nützlich ist, 
; um in der Initialisierungsphase zu debuggen.
debug_init_break = tbreak setup
```

Quellen:
[PlatformIO](https://docs.platformio.org/en/stable/plus/debug-tools/esp-prog.html),
[BerryBase](https://blog.berrybase.de/esp32-debuggen-mit-espressif-esp-prog-platformio/),
[Harald Kreuzer](https://www.haraldkreuzer.net/aktuelles/esp32-jtag-debugging-mit-platformio-und-nur-einer-usb-verbindung)

## Troubleshooting

OpenOCD testen:

```bash
& "C:\Users\frank\.platformio\packages\tool-openocd-esp32\bin\openocd.exe" -d2 -s "C:\Users\frank\.platformio\packages\tool-openocd-esp32\share\openocd\scripts" -f interface/ftdi/esp32_devkitj_v1.cfg -f board/esp-wroom-32.cfg -c "adapter speed 1000"
```

Reset‑Check mit OpenOCD:

```bash
& "C:\Users\frank\.platformio\packages\tool-openocd-esp32\bin\openocd.exe" `
  -d2 -s "C:\Users\frank\.platformio\packages\tool-openocd-esp32\share\openocd\scripts" `
  -f interface/ftdi/esp32_devkitj_v1.cfg -f board/esp-wroom-32.cfg `
  -c "adapter speed 1000" -c "init" -c "reset halt" -c "exit"
```

Flash-Kommando:

```bash
& "C:\Users\frank\.platformio\packages\tool-openocd-esp32\bin\openocd.exe" `
  -d2 -s "C:\Users\frank\.platformio\packages\tool-openocd-esp32\share\openocd\scripts" `
  -f interface/ftdi/esp32_devkitj_v1.cfg -f board/esp-wroom-32.cfg `
  -c "adapter speed 1000" `
  -c "init" `
  -c "reset halt" `
  -c "program_esp C:/Users/frank/Source/PlatformIO/biodom-mini/.pio/build/debug/firmware.bin 0x10000 verify" `
  -c "reset run" `
  -c "shutdown"
```  

Upload via PlatformIO-Befehl:  

```bash
pio run -e debug -t upload
```

ESP32 Chip-ID auslesen:

```bash
python -m esptool chip-id
```

Versionen einer Bibliothek auflisten:

```bash
pio lib show OneWire
```

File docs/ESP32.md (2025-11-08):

# ESP32

## GPIOs

Es wird die Standard-Pin-Belegung der Arduino IDE verwendet.

Folgende GPIOs stehen beim ESP32-DevKitC V2 zur Verfügung, wenn das WLAN-Modul aktiviert ist:

<pre>  
                            ┌────────────────┐
                +3.3V Out ──┤ 3V3 ESP32  GND ├── GND
                  (RESET) ──┤ EN  DevKit G23 ├── GPIO23 I/O SPI_MOSI
         ADC1-0 In GPIO36 ──┤ SP  C V2   G22 ├── GPIO22 I/O I2C_SCL
         ADC1-3 In GPIO39 ──┤ SN         TXD ├── GPIO1 (UART0_TX)
         ADC1-6 In GPIO34 ──┤ G34        RXD ├── GPIO3 (UART0_RX)
         ADC1-7 In GPIO35 ──┤ G35        G21 ├── GPIO21 I/O I2C_SDA
Touch-9 ADC1-4 I/O GPIO32 ──┤ G32        GND ├── GND
Touch-8 ADC1-5 I/O GPIO33 ──┤ G33        G19 ├── GPIO19 I/O SPI_MISO
          DAC1 I/O GPIO25 ──┤ G25        G18 ├── GPIO18 I/O SPI_CLK
          DAC2 I/O GPIO26 ──┤ G26         G5 ├── GPIO5 (Boot)
               I/O GPIO27 ──┤ G27        G17 ├── GPIO17 I/O UART2_TX
        (JTAG_TMS) GPIO14 ──┤ G14        G16 ├── GPIO16 I/O UART2_RX
  (Boot, JTAG_TDI) GPIO12 ──┤ G12         G4 ├── GPIO4 I/O
                      GND ──┤ GND         G0 ├── GPIO0 (Boot) 
        (JTAG_TCK) GPIO13 ──┤ G13         G2 ├── GPIO2 (Boot) 
            (Flash) GPIO9 ──┤ SD2        G15 ├── GPIO15 (Boot, JTAG_TDO) 
           (Flash) GPIO10 ──┤ SD3        SD1 ├── GPIO8 (Flash)
           (Flash) GPIO11 ──┤ CMD        SD0 ├── GPIO7 (Flash)
                   +5V In ──┤ 5V  [USB]  CLK ├── GPIO6 (Flash)
                            └────────────────┘
</pre>

**Legende:**

* **I/O:** Digitale Ein- und Ausgänge. Alle Ausgänge können auch PWM-Signale erzeugen.
* **In:**  Nur digitale Eingänge (GPIO 34 bis 36, 39). Nur für passive Sensoren geeignet.
* **ADC1 Analog-Digital-Wandler 1:**  Analoge Eingänge (12 Bit). ADC2 (GPIO 0, 2, 4, 12 bis 15 und 25 bis 27) ist mit dem WLAN-Modul nicht zuverlässig, bleibt daher im Diagramm unerwähnt.
* **DAC1, DAC2 (Digital-Analog-Wandler 1 und 2):** Analoge Ausgänge (8 Bit).
* **I2C:** I²C-Schnittstelle
* **SPI:** Virtual SPI-Schnittstelle. Hardware SPI wird selten gebraucht, bleibt daher im Diagramm unerwähnt.
* **Touch:** Interne kapazitive Touch-Sensoren. Die übrigen Touch-Sensoren werden aber durch das WLAN-Modul blockiert (GPIO 0, 2, 4, 12 bis 15 und 27).
* **(UART0), UART2:** Serielle Kommunikation. UART0 besser nicht verwenden. Die Pins sind intern mit dem USB-Wandler-Chip verdrahtet. UART2 ist unbenutzt. UART1 hat standardmäßig keine Pins zugewiesen (kann frei auf irgendwelche GPIOs gemappt werden).
* **(RESET):** Immer frei lassen!
* **(Flash):** GPIO 6 bis 11 sind intern mit dem Flash-Speicher verbunden. Diese Pins niemals verwenden!
* **(Boot):** GPIO 0, 2, 5, 12, 15 sind "Strapping-Pins". Besser nicht verwenden, denn der Bootvorgang wird hiermit beeinflusst. Könnten aber zur Not als digitale Ein- und Ausgänge verwenden werden (zu den Bedingungen siehe nachfolgende Tabelle). 
* **(JTAG):** GPIO 12, 13, 14, 15 können als digitale Ein- und Ausgänge verwendet werden, sofern kein Debugger (ESP-Prog) angeschlossen wird.

**Anmerkungen:**

* Der 5V-Pin versorgt den Onboard-Regler, der daraus 3.3V erzeugt. Toleranzbereich: 4.75 - 5.25V
* Max. Stromabgabe am 3.3V-Pin: 500mA
* Die GPIO Pins (General Purpose Input/Output Pins) arbeiten mit min. 2.3 bis max. 3.6 V, empfohlen werden 3.3V. 
	=> Das heißt: 
  * Sensoren mit 3.3V Betriebsspannung können direkt angeschlossen werden. 
  * Für Sensoren mit einem Ausgangspegel über 3.3V muss der Pegel z.B. durch einen Spannungsteiler (bestehend aus zwei Widerständen) auf 3.3V gedrückt werden!
* Laut Datenblatt (5.3 DC Characteristics) ist der Schwellwert für LOW/HIGH dieser:
  * Alles unter 0.825V wird sicher als LOW erkannt.
  * Alles über 2.475V wird sicher als HIGH erkannt.
* Der absolute Maximalstrom, der pro GPIO gezogen werden darf, beträgt 40 mA.
* Für die SPI-Schnittstelle ist GPIO 5 für CS (Chip Select; synonym für SS, Slave Select) vorgegeben. 
  Das ist ungünstig, denn beim Booten muss der Pin HIGH sein. 
  Daher besser, einen anderen digitalen Ausgang für CS zu wählen (und zwar pro Gerät einen).

### Strapping-Pins

| Pin | Funktion | Bedingung |
|---|---|---|
| GPIO 0  | Boot-Modus | Der Pin darf beim Booten nicht LOW sein. | 
| GPIO 2  | Boot-Modus & Logging | Der Pin darf beim Booten nicht LOW sein. | 
| GPIO 5  | Flash-Spannung | Der Pin darf beim Booten nicht HIGH sein.  | 
| GPIO 12 | Flash-Spannung | Der Pin darf beim Booten nicht HIGH sein.  | 
| GPIO 15 | Boot-Logging | Der Pin darf beim Booten nicht LOW sein. | 

## Hinweise zur Stromversorgung

### Schottky-Diode

Wenn das USB-Kabel und eine externe Spannungsversorgung an 5V-Pin angeschlossen sind, 
muss die externe Versorgung stabil sein. Wenn mehr als 5.2V am 5V-Pin anliegen, 
kann ein Rückstrom in das USB-Kabel fließen. Andersherum kann ein Rückstrom in das Netzteil fließen.  

Eine Schottky-Diode schützt das externe Netzteil vor einem Rückstrom:

<pre>
                 1N5817
Netzteil +5V ──────▶├────── ESP32_5V
                +  D1  - (Ring)
</pre>

1N5817:
* 20V Sperrspannung
* 1 A Dauerstrom
* ~0.3-0.5V Spannungsabfall

Allerdings liegt dann ca. 0.4V weniger am ESP32 an.

**Am besten einfach die externe Spannungsversorgung abklemmen, bevor das USB-Kabel eingesteckt wird!** 

### Spannungsteiler

Falls ein Sensor eine Betriebsspannung über 3.3 V hat, muss ein Spannungsteiler sicherstellen, 
dass der HIGH-Pegel nicht 3.3V überschreitet.

Beispiel - 5V-Sensor mit 5V als HIGH-Pegel:

<pre>
5V ──[ R1 ]─┬─[ R2 ]── GND
            │
          3.3V
</pre>

Teilverhältnis R2 / (R1 + R2) = 3.3 / 5 = 0.66

Faustregel: Der Gesamtwiderstand sollte im Bereich 10kΩ bis 100kΩ liegen.

Ich wähle 10 kΩ und 20 kΩ.
Die max. Ausgangsspannung ist somit 5V * (20kΩ / (20kΩ + 10kΩ) ≈ 3.33 V.

**Pinbelegung:**
<pre>
┌────────────────┐
│ V5-Sensor  GND ├──(schwarz)─O── GND 
│            VCC ├──────(rot)─O── +5V
│            OUT ├─►───(gelb)─O──[ R1 ]─┬─[ R2 ]── GND
└────────────────┘                      └────────► GPIO
                                    R1=10k ±1%  
                                    R2=20k ±1%
</pre>

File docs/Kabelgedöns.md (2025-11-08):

# Kabelgedöns

## AWG-Tabelle

| AWG | Durchmesser | Querschnitt  | Max. Dauerstrom | Drahttyp | Anwendung |
|-----|---|---|---|---|---|
| 22  | ca. 0,64 mm	| ca. 0,33 mm² | 2 - 5 A 	 | Litze (flexibel), z.B. Silikonkabel | Stromversorgung für Standard-Servos<br>• Kleinere bis mittlere Motoren<br>• Hauptstromversorgung für kleine Modelle<br>• Leistungsstarke LED-Beleuchtung |
| 23  | ca. 0,57 mm	| ca. 0,26 mm² | 1,5 - 4 A	 | Litze oder Massivdraht	 | Stromversorgung für Empfänger und Micro-Servos<br>• Längere Servo-Verlängerungskabel<br>• Weniger leistungsstarke Motoren | 
| 24  | ca. 0,51 mm	| ca. 0,20 mm² | 1 - 3 A	 | Litze (sehr verbreitet)	 | Signal- und Stromversorgung für Empfänger<br>• Stromversorgung für Micro-Servos<br>• Einzelne Power-LEDs<br>• Stromversorgung für Bordelektronik (z.B. Flugcontroller) | 
| 25  | ca. 0,45 mm	| ca. 0,16 mm² | 0,7 - 2 A	 | Litze	 | Signalübertragung (z.B. ESC, Sensoren)<br>• Stromversorgung für sehr kleine Servos (Sub-Micro)<br>• Interne Verdrahtung von Elektronikkomponenten | 
| 26  | ca. 0,40 mm	| ca. 0,13 mm² | 0,5 - 1.5 A | Litze (typ. für Jumperkabel)	 | Typische Signalleitungen (Servo, ESC)<br>• Stromversorgung für Sensoren (GPS, Gyro)<br>• Einzelne, kleine LEDs (z.B. Status-LEDs)<br>• Sehr leichte Modelle, wo jedes Gramm zählt | 

* Silikonkabel sind deutlich hitzebeständiger als normale PVC-Kabel und vertragen daher bei gleichem Querschnitt höhere Ströme.

## Kabel-, Stecker und Buchsensysteme

* Dupont Jumper Kabel
* IDC (Wannenstecker, Pfostenbuchsen)
* JST-XH (Zusatz "-XH" ist hier wichtig!)
* Molex

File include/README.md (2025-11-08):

Dieses Verzeichnis ist für Projekt-Headerdateien vorgesehen.

Eine Headerdatei ist eine Datei mit C-Deklarationen und Makrodefinitionen, die von mehreren Projektquelldateien gemeinsam genutzt werden. Man bindet sie mit der C-Präprozessor-Direktive `#include` ein:

```cpp
#include "header.h"

int main (void)

{
...
}
```

Weitere Informationen zur Verwendung von Headerdateien finden Sie in der offiziellen GCC-Dokumentation:
https://gcc.gnu.org/onlinedocs/cpp/Header-Files.html

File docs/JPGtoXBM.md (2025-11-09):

# Teilprojekt: JPGtoXBM

## Anforderung

Ich möchte mit der Kamera (ArduCAM Mini 2MP Plus OV2640) ein Jpg aufnehmen. Der ESP32 DevKitC V2 soll das Bild in ein Byte-Array umwandeln, so dass es auf dem 1.3 Zoll OLED Display SSH1106 angezeigt werden kann.
Das Display hat 128x64 Pixel, ist monochrom, 1 Bit pro Pixel.

### Grundsätzliche Konzeption: Die Daten-Pipeline

Die Herausforderung ist Transformation der Bilddaten. Diese ist rechenintensiv. Der ESP32 ist zwar schnell, aber man sollte keine Wunder erwarten. Die Konvertierung eines hochauflösenden Fotos wird einige Sekunden dauern. Für die Anzeige von Standbildern ist das aber völlig akzeptabel. 

Wir müssen eine Kette von Verarbeitungsschritten aufbauen, eine sogenannte Pipeline. Diese sieht konzeptionell so aus:

**JPG-Stream -> [ JPG-Dekompression ] -> [ Skalierung & Graustufen ] -> [ Dithering ] -> [ XBM-Formatierung ] -> XBM-Stream**

Die ArduCam oder die SD-Karte liefert den JPG-Datenstrom an die Pipeline.

1.  **Verarbeitungsschritt 1: JPG-Dekompression:**  
Die JPG-Daten sind komprimiert. Der erste Schritt muss sein, sie zu dekomprimieren, um an die rohen Pixelinformationen (Farbe für jeden einzelnen Bildpunkt) zu gelangen.
Das erledigt die Bibliothek [TJpg_Decoder by Bodmer](https://github.com/Bodmer/TJpg_Decoder).

(TODO: nicht diese: [JPEGDEC by Larry Bank](https://github.com/bitbank2/JPEGDEC))

Sie ist für genau diesen Zweck für zur Ausführung auf Mikrocontroller geschrieben. Um den verfügbaren RAM zu schonen, arbeitet die Bibliothek in kleinen Blöcken (sog. MCUs, oft 8x8 oder 16x16 Pixel). Sie dekomprimiert einen Block, und übergibt diesen an eine **Callback-Funktion**. In dieser Callback-Funktion führen wir dann unsere nachfolgenden Schritte (Skalierung, Dithering, Formatierung) durch, bevor der Decoder den nächsten Block liest.

2.  **Verarbeitungsschritt 2: Skalierung & Graustufen:**  
Das dekomprimierte Bild ist für das Display zu groß und farbig. Wir müssen es auf die Größe des Zieldisplays (128 x 64) herunterskalieren und die Farbinformationen in einen Graustufenwertumwandeln. 

3.  **Verarbeitungsschritt 3: Dithering (Monochrom-Umwandlung):**  
Jetzt haben wir ein kleines Graustufenbild. Da unser Display aber nur "An" (weiß) oder "Aus" (schwarz) kennt, müssen wir entscheiden, welcher Grauwert Schwarz und welcher weiß wird. Ein einfacher Schwellenwert würde zu hässlichen, detailarmen Bildern führen. Der **Dithering-Algorithmus von Floyd-Steinberg** ist hier die Lösung. Er macht folgendes:

    1.  Er nimmt den Grauwert des aktuellen Pixels (z.B. 100).
    2.  Er entscheidet: "Das ist näher an schwarz (0) als an weiß (255)". Er setzt das Pixel also auf Schwarz.
    3.  Er berechnet den "Fehler", den er gemacht hat: `100 - 0 = 100`.
    4.  Diesen Fehler verteilt er anteilig auf die benachbarten Pixel, die noch nicht verarbeitet wurden. Das nächste Pixel, das vielleicht einen Grauwert von 150 hatte, wird dadurch auf z.B. 180 angehoben und hat eine höhere Chance, weiß zu werden.  
    
    Ergebnis: Es entsteht eine Punktwolke, die für das menschliche Auge die Illusion von Grautönen erzeugt. Die Bildqualität ist um Welten besser.

4.  **Verarbeitungsschritt 4: XBM-Formatierung:**  
Das Ergebnis aus Schritt 3 muss nun in das XBM-Format (X BitMap) überführt werden (welches die U8g2-Bibliothek versteht). Das XBM hat diese Eigenschaften:
    - Monochrom: Es speichert nur 1-Bit-Informationen (schwarz/weiß).
    - C-Quellcode: Es ist kein binäres Dateiformat, sondern wird direkt als `C`-Quellcode gespeichert (`static const unsigned char ...`).
    - Feste Struktur: Jedes Byte repräsentiert 8 horizontale Pixel. Die Bits werden "rückwärts" gelesen, d.h. das niedrigstwertige Bit (LSB) ist das linkeste Pixel.

Das Ende der Pipeline ist ein XBM-Datenstrom, der von der `OLEDDisplaySH1106`-Klasse entgegengenommen und als Bild auf auf dem Bildschirm angezeigt werden kann.

### Proof Of Concept

Die Sketche hierzu sind unter `sketches/JPGtoXBM` abgelegt.

1.  **Proof Of Concept 1:** Wie wird ein im XBM-Format umgewandeltes JPG-Bild auf dem Display angezeigt? Ist die Qualität ausreichend? 
    *  Als Bild habe ich mein Portrait gewählt, es mit GIMP auf 128x64 Pixel verkleinert und im JPG-Format gespeichert:  
    JPG-Bild  
    Das JPG-Bild habe ich dann mit dem Tool [Online Image Converter to XBM](https://www.online-utility.org/image/convert/to/XBM) konvertiert:  
    XBM-Bild  
    Die resultierenden XBM-Daten habe ich als Headerdatei unter `frank_128x64_xbm.h` abgelegt. Einmal im `Include`-Verzeichnis (da ich sie auch als Splash-Screen verwenden möchte) und einmal in Ordner, in dem auch der Sketch liegt (damit die Arduino IDE diese einbinden kann).
    *  Um das XBM-Bild anzuzeigen, habe ich den Demo-Sketch `OLED_Display_SSH1106_Test.ino` genommen und alles bis auf das absolut Notwendigste entfernt. 

2.  **Proof Of Concept 2:** Wie kann auf dem ESP32 ein JPG-Bild in ein XBM-Bild umgewandelt werden? Reicht der RAM und wie lange dauert die  Verarbeitungszeit?  

    * In der Arduino IDE habe ich mittels Library Manager `https://github.com/bitbank2/JPEGDecoder` installiert.
    (TODO: nicht diese: `JPEGDEC 1.8.4 by Larry Bank`)
    * Das JPG-Bild aus PoC 1 (./assets/frank_128x64.jpg) habe ich nach folgender Anleitung von Meta-Angaben befreit:  
        1.  Öffne das Bild in GIMP.
        2.  Gehe zu `Datei -> Exportieren als...`.
        3.  Wähle als Dateityp `JPEG-Bild (*.jpg)` und gib ihm einen neuen Namen, z.B. `frank_clean_128x64.jpg` (im selben Ordner in dem auch der Sketch liegt).
        4.  Klicke auf `Exportieren`. Es öffnet sich ein Dialogfenster "Bild als JPEG exportieren".
        5.  Klappe den Bereich `Erweiterte Optionen` auf.
        6.  Entfernte die Haken bei folgenden Optionen:
            *   `EXIF-Daten speichern`
            *   `XMP-Daten speichern`
            *   `IPTC-Daten speichern`
            *   `Vorschaubild speichern`
            *   `Progressiv`
        7.  Klicke auf `Exportieren`.
    * Die Bytes des bereinigten JPG-Bildes habe ich dann in einem C-Array als Headerdatei `image_jpg.h` gespeichert (im selben Ordner wie der Sketch). Das hat das Python-Skript `convert.py` (auch im selben Ordner wie der Sketch) für mich erledigt. Statt dessen kann man auch das Online-Tool [File to hexadecimal converter](http://tomeko.net/online_tools/file_to_hex.php) nutzen - das Ergebnis ist das gleiche.

    🚧🚧🚧 TODO: Ab hier ist der PoC noch nicht umgesetzt! 🚧🚧🚧   
    Der Sketch baut auf dem Sketch von PoC 1 auf. Es lädt aber nicht die XBM-Daten, sondern die JPG-Daten, führt die Konvertierung durch und zeigt schließlich die resultierenden XBM-Daten wie im PoC 1 auf dem Display an.

3.  **Proof Of Concept 3:** Wie können die JPG-Daten von der Kamera bzw. von der SD-Karte als Datenstrom entgegengenommen werden? WIe kann der Datenstrom direkt an das Display weitergeleitet werden?

    Hier abstrahieren wir die Funktion, sodass sie nicht mehr von einer festen Datei abhängt, sondern jeden beliebigen Datenstrom verarbeiten kann.

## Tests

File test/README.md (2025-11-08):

# 🪲 Unit-Test

Dieses Verzeichnis ist für den PlatformIO Test Runner und Projekttests vorgesehen.

Unit-Testing ist eine Softwaretestmethode, bei der einzelne Einheiten des Quellcodes getestet werden, um festzustellen, ob sie einsatzfähig sind.

Die Unit-Tests können über das Labor-Icon der Aktivitätsleiste oder über die Kommandozeile gestartet werden:

```bash
pio test -e debug
```

## 📖 Siehe auch ...

[PlatformIO Unit-Testing](https://docs.platformio.org/en/latest/advanced/unit-testing/index.html)

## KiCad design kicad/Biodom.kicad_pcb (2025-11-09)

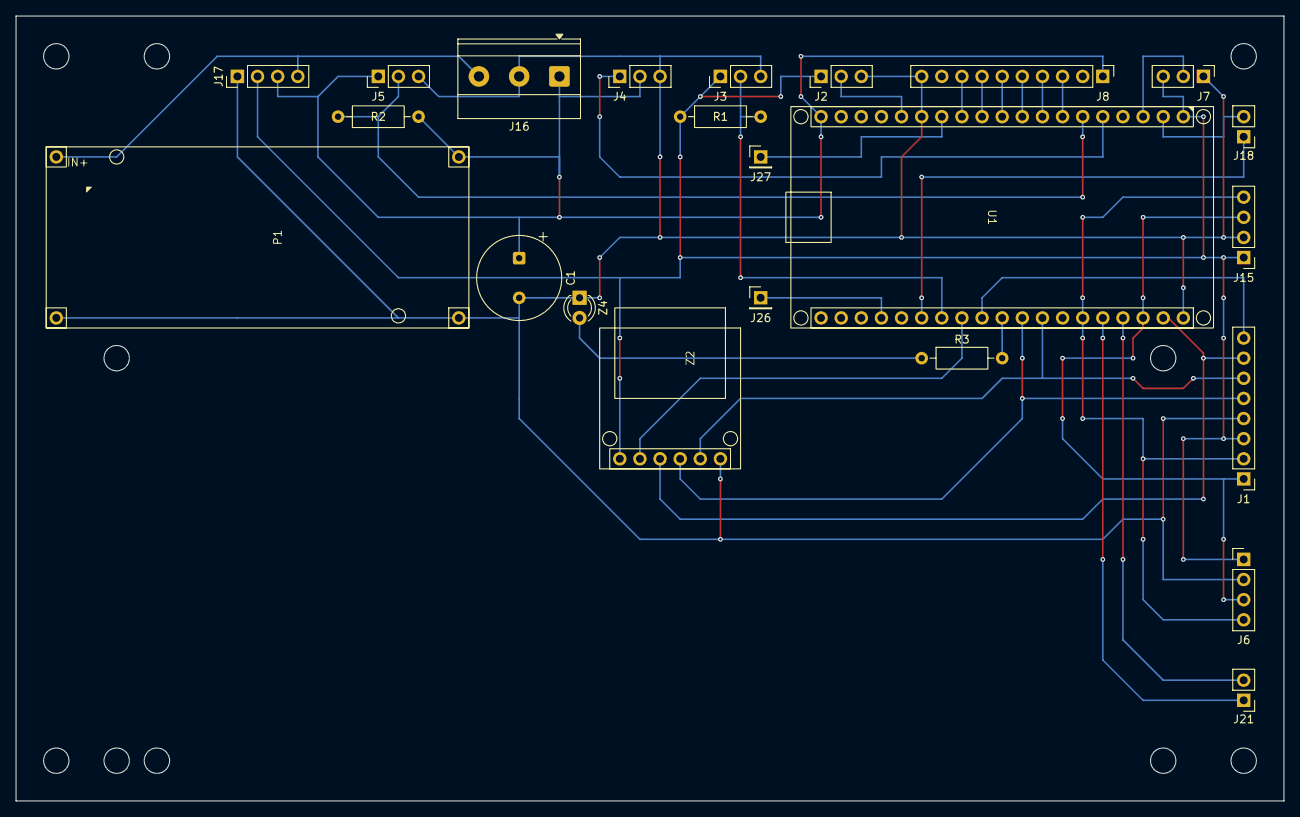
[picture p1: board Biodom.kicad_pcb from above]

Board: 2 copper layers, 160.0 x 99.1 mm, 23 parts (0 on the bottom side), 30 nets.

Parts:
C1: 470µF; CP_Radial_Tantal_D10.5mm_P5.00mm
J1: Kamera; PinHeader_1x08_P2.54mm_Vertical
J2: Luft; PinHeader_1x03_P2.54mm_Vertical
J3: Bodentemperatur; PinHeader_1x03_P2.54mm_Vertical
J4: Bodenfeuchte; PinHeader_1x03_P2.54mm_Vertical
J5: Wasserstand; PinHeader_1x03_P2.54mm_Vertical
J6: Lichtstärke; PinHeader_1x04_P2.54mm_Vertical
J7: Reserve S6; PinHeader_1x03_P2.54mm_Vertical
J8: Relais; PinHeader_1x10_P2.54mm_Vertical
J15: Display; PinHeader_1x04_P2.54mm_Vertical
J16: DC; TerminalBlock_Phoenix_MKDS-1,5-3-5.08_1x03_P5.08mm_Horizont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
J17: PWR; PinHeader_1x04_P2.54mm_Vertical
J18: RST; PinHeader_1x02_P2.54mm_Vertical
J21: UART; PinHeader_1x02_P2.54mm_Vertical
J26: TDO; PinHeader_1x01_P2.54mm_Vertical
J27: TDI; PinHeader_1x01_P2.54mm_Vertical
P1: Spannungsteiler; XL4015_Module_Socket
R1: 4,7kΩ; R_Axial_DIN0207_L6.3mm_D2.5mm_P10.16mm_Horizontal
R2: 10kΩ; R_Axial_DIN0207_L6.3mm_D2.5mm_P10.16mm_Horizontal
R3: 330Ω; R_Axial_DIN0207_L6.3mm_D2.5mm_P10.16mm_Horizontal
U1: ESP32; ESP32_DevKitC_V2_Socket
Z2: SD-Karte; MicroSD_SPI_Modul_Socket
Z4: LED; LED_D3.0mm

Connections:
+3V3: J1.3, J2.1, J3.1, J6.1, J7.3, J15.1, J17.2, R1.1, U1.1 (3V3), Z2.1 (3.3V)
+5V: C1.1, J4.2, J5.1, J8.1, J16.1, J17.3, P1.3 (OUT+), R2.1, U1.19 (5V)
+12V: J16.3, J17.4, P1.1 (IN+)
/EN: J18.2, U1.2 (EN)
/G0: J18.1, U1.25 (G0)
/G1: J21.2, U1.35 (TXD)
/G3: J21.1, U1.34 (RXD)
/G4: J3.2, R1.2, U1.26 (G4)
/G5: R3.2, U1.29 (G5)
/G12: J27.1, U1.13 (G12)
/G13: J2.2, U1.15 (G13)
/G14: J8.8, U1.12 (G14)
/G15: J26.1, U1.23 (G15)
/G16: U1.27 (G16), Z2.2 (CS)
/G17: J1.8, U1.28 (G17)
/G18: J1.5, U1.30 (G18), Z2.4 (CLK)
/G19: J1.6, U1.31 (G19), Z2.5 (MISO)
/G21: J1.2, J6.4, J15.4, U1.33 (G21)
/G22: J1.1, J6.3, J15.3, U1.36 (G22)
/G23: J1.7, U1.37 (G23), Z2.3 (MOSI)
/G25: J8.5, U1.9 (G25)
/G26: J8.6, U1.10 (G26)
/G27: J8.7, U1.11 (G27)
/G32: J8.3, U1.7 (G32)
/G33: J8.4, U1.8 (G33)
/G34: J4.1, U1.5 (G34)
/G35: J5.2, R2.2, U1.6 (G35)
/G36: J7.2, U1.3 (SP)
/LED+: R3.1, Z4.2 (A)
GND: C1.2, J1.4, J2.3, J3.3, J4.3, J5.3, J6.2, J7.1, J8.10, J15.2, J16.2, J17.1, P1.2 (IN-), P1.4 (OUT-), U1.14 (GND), U1.38 (GND), Z2.6 (GND), Z4.1 (K)

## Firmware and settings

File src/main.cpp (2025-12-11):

/**
 * @file main.cpp
 * @brief Hauptprogramm für das "Biodom Mini" Projekt.
 *
 * Diese Datei enthält die Hauptlogik zur Steuerung des Gewächshauses.
 * Sie initialisiert alle Sensoren und Aktoren, liest periodisch Messwerte aus,
 * wendet die Steuerungslogik an und aktualisiert die Anzeige.
 *
 * @version 1.0.9
 * @date 11.12.2025
 * @author Frank Rohlfing
 *
 * Derzeit können die Kameraeinstellungen noch nicht gespeichert werden.
 */

#include <Arduino.h>
#include <WiFi.h>
// #include <ArduinoOTA.h>
#include <ArduinoJson.h>
#include <LittleFS.h>
#include <SD.h>
#include <Wire.h>

// -- Einbinden der Konfiguration und der lokalen Bibliotheken --
#include "config.h"
#include "secrets.h"
#include "settings.h"
#include "SettingsManager.h"
#include "WebUI.h"
#include "ArduCamOV2640.h"
#include "LED.h"
#include "MicroSDCard.h"
#include "OLEDDisplaySH1106.h"
#include "OTA.h"
#include "Relay.h"
#include "SensorAM2302.h"
#include "SensorBH1750.h"
#include "SensorCapacitiveSoil.h"
#include "SensorDS18B20.h"
#include "SensorXKCY25NPN.h"

// Splash Screen
#include "xbm/frank_128x64_xbm.h" // definiert das C-Array frank_128x64_bits[]

// Icons für das Dashboard
#include "xbm/thermometer_16x16_xbm.h"    // Icon für Raumtemperatur (S1)
#include "xbm/wet_16x16_xbm.h"            // Icon für Luftfeuchtigkeit (S1)
#include "xbm/engine_coolant_16x16_xbm.h" // Icon für Bodentemperatur (S2)
#include "xbm/moisture_16x16_xbm.h"       // Icon für Bodenfeuchte (S3)

// Icons, wenn Aktoren aktiv sind
#include "xbm/radiator_16x16_xbm.h"      // Heizung (A3) aktiviert (überlagert Icon für Bodentemperatur)
#include "xbm/air_16x16_xbm.h"           // Lüfter (A4) aktiviert (überlagert Icons für Raumtemperatur und Luftfeuchtigkeit)
#include "xbm/rainy_weather_16x16_xbm.h" // Pumpe (A5) aktiviert (überlagert Icon für Bodenfeuchte)
#include "xbm/dry_16x16_xbm.h"           // Vernebler (A6) aktiviert (überlagert Icon für Luftfeuchtigkeit)

// === Globale Objektinstanzen ===

// --- Einstellungen ---
SettingsManager settingsManager;

// --- Webinterface ---
WebUI webInterface;

OTA ota(HOSTNAME, OTA_PASSWORD);

// --- Sensoren ---
SensorAM2302 airSensor(PIN_AIR_SENSOR); // Raumtemperatur- und Luftfeuchtigkeitssensormodul AM2302 (S1)
SensorDS18B20 soilTempSensor(PIN_SOIL_TEMPERATUR_SENSOR); // Bodentemperatursensor DS18B20 (S2)
SensorCapacitiveSoil soilMoistureSensor(PIN_SOIL_MOISTURE_SENSOR, SOIL_MOISTURE_ADC_DRY, SOIL_MOISTURE_ADC_WET); // Kapazitiver Bodenfeuchtigkeitssensor v1.2 (S3)
SensorXKCY25NPN waterLevelSensor(PIN_WATER_LEVEL_SENSOR); // Berührungsloser Füllstandsensor XKC-Y25-NPN (S4)
SensorBH1750 lightSensor; // Lichtsensor GY-302 BH1750 (S5)

// --- Aktoren (Relais) ---
// Die Relais sind active-low, d.h. LOW schaltet sie ein.
Relay lamp1Relay(PIN_LAMP1_RELAY);    // Lampe 1 (A1)
Relay lamp2Relay(PIN_LAMP2_RELAY);    // Lampe 2 (A2)
Relay heaterRelay(PIN_HEATER_RELAY);  // Heizer (A3)
Relay fanRelay(PIN_FAN_RELAY);        // Lüfter (A4)
Relay pumpRelay(PIN_PUMP_RELAY);      // Wasserpumpe (A5)
Relay misterRelay(PIN_MISTER_RELAY);  // Vernebler (A6)

// --- Sonstige Peripherie ---
OLEDDisplaySH1106 display;            // 1.3 Zoll OLED Display, SSH1106 (Z1)
MicroSDCard sdCard(PIN_SPI_SD_CS);    // MicroSD SPI Kartenleser (Z2)
ArduCamOV2640 camera(PIN_SPI_CAMERA_CS); // ArduCAM OV2640 Mini 2MP Plus (Z3)
LED debugLed(PIN_DEBUG_LED);          // LED (Z4)

// === Globale Variablen zur Zustandsspeicherung ===

// --- Sensorwerte ---
// Diese Variablen speichern die zuletzt gemessenen Werte, um sie im Programmablauf zu verwenden.
// Sie werden mit "Not a Number" (NAN) oder -1 initialisiert, um anzuzeigen, dass noch keine gültige Messung stattgefunden hat.
float currentAirTemp = NAN;         // Aktuelle Raumtemperatur in °C (S1)
float currentHumidity = NAN;        // Aktuelle Luftfeuchtigkeit in % (S1)
float currentSoilTemp = NAN;        // Aktuelle Bodentemperatur in °C (S2)
int currentSoilMoisture = -1;       // Aktuelle Bodenfeuchte in % (S3), -1 bedeutet "ungültig/nicht gemessen"
bool isWaterLevelOk = false;        // Zustand des Wasserfüllstands (S4), startet mit 'false' (kein Wasser), bis erste Messung erfolgt.
float currentLightLux = NAN;        // Aktuelle Lichtstärke in Lux (S5)

// --- Zeitsteuerung für nicht-blockierende Operationen ---
// Diese Variablen speichern den Zeitpunkt (in Millisekunden seit Start) der letzten Ausführung,
// um Aktionen in festen Intervallen ohne blockierende delay()-Aufrufe durchzuführen.
unsigned long lastSensorRead = 0;     // Zeitpunkt der letzten Sensormessung
unsigned long lastDisplayUpdate = 0;  // Zeitpunkt der letzten Display-Aktualisierung
unsigned long lastCameraCapture = 0;  // Zeitpunkt der letzten Kameraaufnahme
unsigned long lastBroadcastTime = 0;  // Zeitpunkt der letzten Broadcast-Nachricht

// === Funktionsprototypen ===

void printFileSystemInfo();
bool readSensors();
void controlActors();
void controlCamera();
void updateDisplay();
void applyCameraSettings();
bool capture();
JsonObject getStateAsJson(JsonDocument& doc);
void broadcastState();
void broadcastSettings();
void handleWSClientConnect(AsyncWebSocketClient* client);
void handleWSMessage(AsyncWebSocketClient* client, const String& msg);
/**
 * Hält das Programm an.
 *
 * Gibt vor dem Halt eine Meldung und optional weitere Details aus.
 * Zusätzlich wird die Debug-LED eingeschaltet.
 * @param message Die Fehlermeldung, die auf dem Display und seriell ausgegeben wird.
 * @param detail Details zur Fehlermeldung (optional).
 */
void halt(const char* message, const char* detail = "") {
    Serial.println(message);
    display.addLogLine(message);
    if (strlen(detail) > 0) {
        Serial.println(detail);
        display.addLogLine(detail);
    }
    Serial.println(F("System angehalten"));
    display.addLogLine(F("System angehalten"));

    // LED dauerhaft einschalten, um den Halt zu signalisieren.
    debugLed.on();

    delay(1000);
    ESP.restart();

    // // Endlosschleife, um das Programm anzuhalten
    // while (true) {
    //     delay(100); // Prozessor entlasten
    // }
}

/**
 * Gibt den Logeintrag aus.
 *
 * Es wird etwas gewartet, damit der Eintrag auch auf dem Display gelesen werden kann,
 * bevor eventuell der nächste Eintrag angezeigt wird.
 */
void log(const char* message) {
    Serial.println(message);
    display.addLogLine(message);
    delay(LOG_DELAY);
}

/*
Symptom:
Nach einem "Soft Reset" (Software-Upload, OTA oder Reset-Knopf) bleibt die Bootsequenz bei "SD-Karte ok" hängen.
Wenn die Stromversorgung kurz aus und wieder eingeschaltet wird, startet der ESP ohne Probleme.

Die Ursache:
Wenn du einen "Soft Reset" machst (Software-Upload, OTA oder Reset-Knopf), wird die Stromversorgung nicht unterbrochen.

- I2C-Problem:
Ein I2C-Slave (z.B. der Kamerasensor oder das Display) könnte gerade ein Bit gesendet haben (SDA auf LOW ziehen), als
der Reset kam. Der ESP32 startet neu, sieht, dass die Datenleitung (SDA) blockiert ist ("Low"), und die Wire-Bibliothek
bleibt in einer Endlosschleife hängen, weil sie darauf wartet, dass der Bus frei wird.

- SPI-Konflikt:
Die SD-Bibliothek initialisiert den SPI-Bus oft mit sehr hohen Geschwindigkeiten. Wenn danach die camera.begin()
aufgerufen wird, ist der SPI-Bus vielleicht noch in einem Zustand oder Modus, den die ArduCAM-Bibliothek nicht erwartet
(oder die SD-Karte "hält" noch die MISO-Leitung).

Die Lösung:
Wir müssen in der setup() zwei Dinge tun:
1) I2C-Bus "freischaufeln": Bevor wir Wire.begin() aufrufen, wackeln wir manuell am Takt-Pin (SCL), bis alle Slaves die
Datenleitung (SDA) loslassen.
2) SPI-Bus beruhigen: Zwischen der Initialisierung der SD-Karte und der Kamera fügen wir eine Zwangspause ein und
stellen sicher, dass der Chip-Select (CS) der SD-Karte deaktiviert ist.
*/

/**
 * @brief Initialisierungsroutine
 */
void setup() {
    // Zufallsgenerator mit einem unvorhersehbaren Wert von einem offenen Analog-Pin initialisieren
    randomSeed(analogRead(36)); // der GPIO36 ist ungenutzt

    // --- Debug-LED, serielle Schnittstelle und Display initialisieren ---
    // (als erstes, damit Fehler so früh wie möglich angezeigt werden können)

    // Debug-LED (Z4) initialisieren
    // Die LED ist standardmäßig aus. Sie signalisiert, dass da System nicht gestartet werden konnte.
    debugLed.begin();

    // Serielle Schnittstelle initialisieren
    Serial.begin(115200);
    // Auf ein Zeichen des Seriellen Monitors warten (max. 5 Sekunden)
    const unsigned long startWait = millis();
    while (millis() - startWait < 5000) {
        if (Serial.available() > 0) {
            break; // Benutzer hat etwas gesendet, starte sofort
        }
        delay(100);
    }

    Serial.println("Biodom Mini startet");

    // I2C-Bus initialisieren
    // Für den ESP32 ist es eine gute Praxis, die SDA- und SCL-Pins explizit anzugeben.
    Wire.begin(PIN_I2C_SDA, PIN_I2C_SCL);

    // Alle CS-Pins auf HIGH setzen und SPI-Bus initialisieren
    pinMode(PIN_SPI_SD_CS, OUTPUT);
    digitalWrite(PIN_SPI_SD_CS, HIGH);
    pinMode(PIN_SPI_CAMERA_CS, OUTPUT);
    digitalWrite(PIN_SPI_CAMERA_CS, HIGH);
    SPI.begin();

    // Display (Z1) initialisieren
    if (!display.begin()) {
        Serial.println("Kein Display! System angehalten.");
        // halt() wird hier noch nicht aufgerufen werden, da die Funktion das Display voraussetzt
        debugLed.on();
        while (true) { delay(100); } // Endlosschleife, um das Programm anzuhalten
    }

    // Dateisystem initialisieren
    if (!LittleFS.begin(true)) {
        halt("LittleFS FEHLER", "Dateisystem korrupt");
    }
    //printFileSystemInfo();

    // Einstellungen laden
    if (!settingsManager.begin()) {
        halt("Settings FEHLER", "Einstellungen korrupt");
    }
    log("Einstellungen geladen");

    // --- Netzwerkdienste starten ---

    // Netzwerk initialisieren
    log("Verbinde mit WLAN...");
    WiFiClass::mode(WIFI_STA); // Station Mode (Client)
    WiFiClass::setHostname(HOSTNAME);
    WiFi.begin(WIFI_SSID, WIFI_PASSWORD);
    int attempts = 0;
    while (WiFi.status() != WL_CONNECTED && attempts < 20) { // max. 20 * 500ms = 10 Sekunden lang versuchen NOLINT(*-static-accessed-through-instance)
        delay(500);
        Serial.print(".");
        attempts++;
    }
    Serial.println();
    if (WiFi.status() != WL_CONNECTED) { // NOLINT(*-static-accessed-through-instance)
        halt("WLAN FEHLER", "Verbindung fehlgeschlagen");
    }
    log("WLAN verbunden!");
    String ipMessage = "IP: " + WiFi.localIP().toString();
    log(ipMessage.c_str());
    String hostMessage = "Host: " + String(WiFiClass::getHostname());
    log(hostMessage.c_str());

    // OTA-Dienst starten
    ota.begin();
    log("OTA-Dienst bereit");

    // NTP-Client initialisieren
    configTime(GMT_OFFSET, DAYLIGHT_OFFSET, NTP_SERVER); // started Hintergrund-Task für Zeitsynchronisation
    log("Synchronisiere Zeit...");
    attempts = 0;
    tm timeInfo{};
    while (!getLocalTime(&timeInfo) && attempts < 20) { // max. 20 * 500ms = 10 Sekunden lang versuchen
        delay(500);
        Serial.print(".");
        attempts++;
    }
    Serial.println();
    if (!getLocalTime(&timeInfo)) {
        halt("NTP FEHLER", "Zeit nicht ermittelt");
    }
    char timeString[20];
    strftime(timeString, sizeof(timeString), "%d.%m.%Y %H:%M:%S", &timeInfo);
    log(timeString);

    // --- Restliche Hardware-Komponenten initialisieren ---

    log("Systemstart...");

    // S1
    if (!airSensor.begin()) {
        halt("Luftsensor FEHLER", airSensor.getErrorMessage());
    }
    log("Luftsensor OK");

    // S2
    if (!soilTempSensor.begin()) {
        halt("Bodentemp. FEHLER");
    }
    log("Bodentemperatur OK");

    // S3
    if (!soilMoistureSensor.begin()) {
        halt("Bodenfeuchte FEHLER");
    }
    log("Bodenfeuchtesensor OK");

    // S4
    if (!waterLevelSensor.begin()) {
        halt("Wasserstand FEHLER");
    }
    log("Wasserstandsensor OK");

    // S5 (I2C-Gerät)
    if (!lightSensor.begin()) {
        halt("Lichtsensor FEHLER");
    }
    log("Lichtsensor OK");

    // Sonstige Peripheriegeräte

    // Z2
    if (!sdCard.begin()) {
        halt("SD-Karte FEHLER");
    }
    log("SD-Karte OK");

    // Z3 (I2C-Gerät)
    if (!camera.begin()) {
        halt("Kamera FEHLER");
    }
    log("Kamera OK");

    // todo friert den Bootvorgang scheinbar ein!
    //applyCameraSettings();
    //log("Kamera konfiguriert");

    // Relais initialisieren
    lamp1Relay.begin();  // A1
    lamp2Relay.begin();  // A2
    heaterRelay.begin(); // A3
    fanRelay.begin();    // A4
    pumpRelay.begin();   // A5
    misterRelay.begin(); // A6
    log("Aktoren initialisiert");

    // --- Webinterface initialisieren ---

    if (!webInterface.begin(&SD)) {
        halt("WebServer FEHLER", "WebServer nicht ok");
    }

    // Callback für neue Client-Verbindungen
    webInterface.onClientConnect = handleWSClientConnect;

    // Callback für eingehende Nachrichten
    webInterface.onMessage = handleWSMessage;

    // --- Initialisierung erfolgreich ---

    Serial.println("System gestartet.");

    // Splash-Screen kurz anzeigen (signalisiert, dass alles ok ist
    display.showFullscreenXBM(128, 64, frank_128x64_xbm);
    delay(1000);

    // Initiales Auslesen aller Sensoren
    readSensors();
}

/**
 * @brief Hauptschleife, wird kontinuierlich ausgeführt.
 */
void loop() {
    ota.handle();
    webInterface.cleanupClients();
    const unsigned long currentTime = millis();

    // Nicht-blockierende Handler aufrufen

    if (currentTime - lastSensorRead >= SENSOR_READ_INTERVAL) {
        lastSensorRead = currentTime;
        readSensors();
    }

    if (currentTime - lastDisplayUpdate >= DISPLAY_UPDATE_INTERVAL) {
        lastDisplayUpdate = currentTime;
        updateDisplay();
    }

    if (currentTime - lastCameraCapture >= CAMERA_CAPTURE_INTERVAL) {
        lastCameraCapture = currentTime;
        capture();
    }

    // Periodischer Broadcast per WebSocket
    if (currentTime - lastBroadcastTime >= BROADCAST_INTERVAL) {
        lastBroadcastTime = currentTime;
        broadcastState();
    }

    // Steuerungslogik in jedem Zyklus ausführen, um schnell reagieren zu können
    controlActors();

    // Kamera-Logik
    controlCamera();

    // Update-Funktionen für zeitgesteuerte Komponenten aufrufen
    debugLed.update();
    fanRelay.update();
    pumpRelay.update();
    display.update();
}

// --- Händler ---

/**
 * @brief Wird aufgerufen, wenn sich ein neuer WebSocket-Client verbindet.
 * @param client Ein Pointer auf den neuen Client.
 */
void handleWSClientConnect(AsyncWebSocketClient* client) {
    // Sende dem neuen Client sofort den letzten bekannten Live-Status (nur an diesen Client)
    JsonDocument stateDoc;
    webInterface.sendTo(client, "state", getStateAsJson(stateDoc));

    // Sende dem neuen Client die aktuellen Einstellungen
    JsonDocument settingsDoc;
    const JsonObject values = settingsDoc.to<JsonObject>();
    settingsManager.serialize(values);
    webInterface.sendTo(client, "settings", values);
}

/**
 * @brief Verarbeitet eingehende Nachrichten von einem WebSocket-Client.
 * @param client Ein Pointer auf den Client, der die Nachricht gesendet hat.
 * @param msg Die empfangene Nachricht als String.
 */
void handleWSMessage(AsyncWebSocketClient* client, const String& msg) {
    // Parse die empfangene Nachricht als JSON-Dokument.
    JsonDocument doc;
    const DeserializationError error = deserializeJson(doc, msg);
    if (error) {
        webInterface.consoleLog(client, "WebSocket JSON-Fehler: %s", error.c_str());
        return;
    }

    // Extrahiere den Nachrichtentyp.
    const char* type = doc["type"];
    if (!type) {
        webInterface.consoleLog(client, "WebSocket-Fehler: Nachricht ohne 'type'-Feld.");
        return;
    }

    // --- Aktor schalten ---

    if (strcmp(type, "setMode") == 0) {
        const JsonObject payload = doc["payload"];
        const char* modeStr = payload["mode"];
        ControlMode mode;
        if (strcmp(modeStr, "auto") == 0) mode = MODE_AUTO;
        else if (strcmp(modeStr, "on") == 0) mode = MODE_ON;
        else if (strcmp(modeStr, "off") == 0) mode = MODE_OFF;
        else {
            webInterface.consoleLog(client, "WebSocket-Fehler: 'mode' fehlerhaft.");
            return;
        }
        Settings& settings = settingsManager.getMutable();
        const char* targetStr = payload["target"];
        if (strcmp(targetStr, "lamp1") == 0) { settings.lamp1Mode = mode; }
        else if (strcmp(targetStr, "lamp2") == 0) { settings.lamp2Mode = mode; }
        else if (strcmp(targetStr, "heater") == 0) { settings.heaterMode = mode; }
        else if (strcmp(targetStr, "fan") == 0) { settings.fanMode = mode; }
        else if (strcmp(targetStr, "pump") == 0) { settings.pumpMode = mode; }
        else if (strcmp(targetStr, "mister") == 0) { settings.misterMode = mode; }
        settingsManager.save(); // Speichere die neuen Modi persistent
        controlActors(); // Wende den neuen Zustand sofort an (Relais schalten)
        broadcastSettings();
        broadcastState();
    }

    // --- Einstellungen speichern ---

    else if (strcmp(type, "saveSettings") == 0) {
        webInterface.consoleLog(client, "Befehl 'saveSettings' empfangen.");
        const JsonObject payload = doc["payload"].as<JsonObject>();
        if (payload) {
            settingsManager.deserialize(payload);
            applyCameraSettings(); // Neue Kamera-Einstellungen sofort anwenden
            if (settingsManager.save()) {
                broadcastSettings();
            } else {
                webInterface.consoleLog(client, "FEHLER: Konnte nicht speichern.");
            }
        }
    }

    // --- Bild aufnehmen ---

    else if (strcmp(type, "captureNow") == 0) {
        webInterface.consoleLog(client, "Manuelle Aufnahme...");
        if (!capture()) {
            webInterface.broadcast("captureFailed");
        }
    }

    // --- Bildliste anfordern ---

    else if (strcmp(type, "getImageList") == 0) {
        webInterface.consoleLog(client, "Befehl: Bildliste anfordern");

        if (!sdCard.isReady()) {
            webInterface.consoleLog(client, "Fehler: SD-Karte nicht bereit für Bildliste.");
            // Optional: Eine Fehlermeldung an den Client senden
            return;
        }

        JsonDocument doc2;
        JsonArray images = doc2.to<JsonArray>();

        sdCard.listDir("/", [&images](const String& filename, const size_t size) {
            if (filename.endsWith(".jpg")) {
                const JsonObject img = images.add<JsonObject>();
                img["path"] = "/" + filename;
                img["size"] = size;
            }
        });

        // Sende die Liste als 'imageList'-Nachricht an den anfragenden Client
        JsonDocument responseDoc;
        responseDoc["type"] = "imageList";
        responseDoc["payload"]["images"] = images;
        String response;
        serializeJson(responseDoc, response);
        client->text(response);
    }

    // --- Alle Bilder löschen ---

    else if (strcmp(type, "deleteAllImages") == 0) {
        webInterface.consoleLog(client, "Befehl: Bilder löschen");
        // Payload extrahieren
        const JsonObject payload = doc["payload"];
        const char* password = payload["password"];

        if (password && strcmp(password, OTA_PASSWORD) == 0) {
            if (sdCard.deleteAllFilesInDir("/")) {
                webInterface.consoleLog(client, "SD-Karte bereinigt.");
                webInterface.broadcast("imageListCleared");
            } else {
                webInterface.consoleLog(client, "Fehler beim Löschen.");
            }
        } else {
            webInterface.consoleLog(client, "Falsches Passwort!");
        }
    }

    else {
        webInterface.consoleLog(client, "Unbekannter WebSocket-Nachrichtentyp: %s\n", type);
    }
}

// --- Hilfsfunktionen ---

/**
 * @brief Gibt Informationen über das Dateisystem (LittleFS) auf der seriellen Konsole aus.
 * Zeigt Gesamtgröße, belegten/freien Speicher und eine Liste der Dateien.
 */
void printFileSystemInfo() {
    Serial.println("--- LittleFS Dateisystem ---");
    const size_t totalBytes = LittleFS.totalBytes();
    const size_t usedBytes = LittleFS.usedBytes();
    const size_t freeBytes = totalBytes - usedBytes; // der freie Speicherplatz
    Serial.printf("Gesamtgröße:  %10u Bytes (%.2f KB)\n", totalBytes, totalBytes / 1024.0);
    Serial.printf("Belegt:       %10u Bytes (%.2f KB)\n", usedBytes, usedBytes / 1024.0);
    Serial.printf("Frei:         %10u Bytes (%.2f KB)\n", freeBytes, freeBytes / 1024.0);

    Serial.println("Dateien im LittleFS:");
    File root = LittleFS.open("/");
    File file = root.openNextFile();
    if (!file) {
        Serial.println("  (Keine Dateien gefunden)");
    }
    while (file) {
        Serial.printf("  - %-20s (%u Bytes)\n", file.name(), file.size());
        file = root.openNextFile();
    }
}

/**
 * @brief Liest alle Sensoren aus und speichert die Werte in globalen Variablen.
 */
bool readSensors() {
    debugLed.on(); // LED an während des Lesens

    if (airSensor.read()) {
        currentAirTemp = airSensor.getTemperature();
        currentHumidity = airSensor.getHumidity();
    }

    if (soilTempSensor.read()) {
        currentSoilTemp = soilTempSensor.getTemperature();
    }

    if (soilMoistureSensor.read()) {
        currentSoilMoisture = soilMoistureSensor.getPercent();
    }

    if (lightSensor.read()) {
        currentLightLux = lightSensor.getLux();
    }

    if (waterLevelSensor.read()) {
        isWaterLevelOk = waterLevelSensor.isWaterDetected();
    }

    debugLed.off(); // LED aus nach dem Lesen
    return true;
}
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

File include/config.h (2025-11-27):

#pragma once 

/**
 * Zentrale Konfigurationsdatei für das Biodom Mini Projekt.
 */

// ------------------------------------------------------------
// GPIO-Pins für Sensoren, Aktoren und Peripheriegeräte
// ------------------------------------------------------------

// Sensoren
constexpr int PIN_AIR_SENSOR = 13; // GPIO-Pin für den Raumtemperatur- und Luftfeuchtigkeitssensormodul AM2302 (S1)
constexpr int PIN_SOIL_TEMPERATUR_SENSOR = 4; // GPIO-Pin für den Bodentemperatursensor DS18B20 (S2)
constexpr int PIN_SOIL_MOISTURE_SENSOR = 34; // GPIO-Pin für den Kapazitiver Bodenfeuchtigkeitssensor v1.2 (S3)
constexpr int PIN_WATER_LEVEL_SENSOR = 35; // GPIO-Pin für den Füllstandsensor XKC-Y25-NPN (S4)

// I2C-Geräte (Kamera, Display und Lichtsensor GY-302 BH1750 (S5)
constexpr int PIN_I2C_SDA = 21; // GPIO-Pin für I2C SDA (Data) Leitung
constexpr int PIN_I2C_SCL = 22; // GPIO-Pin für I2C SCL (Clock) Leitung

// SPI-Geräte (Kamera und SD-Karte)
constexpr int PIN_SPI_MOSI = 23; // GPIO-Pin für SPI MOSI Leitung
constexpr int PIN_SPI_MISO = 19; // GPIO-Pin für SPI MISO Leitung
constexpr int PIN_SPI_SCK = 18; // GPIO-Pin für SPI Clock Leitung
constexpr int PIN_SPI_SD_CS = 16; // GPIO-Pin für SPI Chip Select der SD-Karte
constexpr int PIN_SPI_CAMERA_CS = 17; // GPIO-Pin für SPI Chip Select der Kamera

// Aktoren
constexpr int PIN_LAMP1_RELAY = 14; // GPIO-Pin für das Relais der Pflanzenlampe 1 (A1)
constexpr int PIN_LAMP2_RELAY = 27; // GPIO-Pin für das Relais der Pflanzenlampe 2 (A2)
constexpr int PIN_HEATER_RELAY = 26; // GPIO-Pin für das Relais der Heizmatte (A3)
constexpr int PIN_FAN_RELAY = 25; // GPIO-Pin für das Relais des Lüfters (A4)
constexpr int PIN_PUMP_RELAY = 33; // GPIO-Pin für das Relais der Wasserpumpe (A5)
constexpr int PIN_MISTER_RELAY = 32; // GPIO-Pin für das Relais des Luftbefeuchters (A6)

// Sonstige Peripheriegeräte
constexpr int PIN_DEBUG_LED = 5; // GPIO-Pin für die Debug-LED

// ------------------------------------------------------------
// NTP (Network Time Protocol) 
// ------------------------------------------------------------

const char* NTP_SERVER = "pool.ntp.org"; // NTP-Server
constexpr long GMT_OFFSET = 3600; // Mitteleuropäische Zeit (MEZ) = UTC+1 = 3600 Sekunden für Zeitzone "Berlin"
constexpr int DAYLIGHT_OFFSET = 3600; // Sommerzeit (MESZ) = UTC+2, also zusätzliche 3600 Sekunden (Sommer-/Winterzeit wird automatisch umgestellt)

// ------------------------------------------------------------
// Kalibrierung
// ------------------------------------------------------------

// Bodenfeuchte
constexpr int SOIL_MOISTURE_ADC_DRY = 2500; // ADC-Wert, wenn der Sensor in der Luft hängt (komplett trocken)
constexpr int SOIL_MOISTURE_ADC_WET = 1100; // ADC-Wert, wenn der Sensor in Wasser getaucht ist (komplett nass)

// ------------------------------------------------------------
// Flags
// ------------------------------------------------------------

constexpr bool WATER_LEVEL_TRIGGERED = false; // Wasserstand (S4) - LOW/false = Wasser erkannt

// ------------------------------------------------------------
// Intervalle
// ------------------------------------------------------------

constexpr unsigned long LOG_DELAY = 100; // Verzögerung in ms nach einem Log-Eintrag im Display (während des Bootens)
constexpr unsigned long SENSOR_READ_INTERVAL = 5000; // Intervall in ms, um Sensoren zu lesen (alle 5 Sekunden)
constexpr unsigned long DISPLAY_UPDATE_INTERVAL = 1000; // Intervall in ms, um das Display zu aktualisieren (jede Sekunde in ms)
constexpr unsigned long BROADCAST_INTERVAL = 2000; // Intervall in ms für ein WebSocket Broadcast (jede zweite Sekunde in ms)
constexpr unsigned long CAMERA_CAPTURE_INTERVAL = 3600000; // Intervall in ms, um ein Bild zu machen (alle 60 Minuten in ms)

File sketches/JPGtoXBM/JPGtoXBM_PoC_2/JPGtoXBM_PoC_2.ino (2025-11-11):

// JPGtoXBM_PoC_2.ino
// PoC2: TJpg_Decoder (Bodmer) + Floyd-Steinberg Dithering (optional) -> XBM Buffer -> u8g2 SH1106
// Bit-Layout: xbm_buffer, 1 bit per pixel, bit==1 -> black pixel

#include <Arduino.h>
#include <U8g2lib.h>
#include <TJpg_Decoder.h>

#ifdef U8X8_HAVE_HW_I2C
#include <Wire.h>
#endif

// ==================== Konfiguration ====================
#define USE_TEST_PATTERN     false   // true = einfacher horizontaler Strich, false = echtes JPG aus frank_128x64_clean_jpg.h
#define USE_DITHERING        true    // true = Floyd–Steinberg Dithering, false = simples Thresholding
#define USE_NEGATIVE_DISPLAY true    // true = Negativ auf OLED (weißer Hintergrund, "stanzen" der schwarzen Pixel)

// Display / Bildgrößen
#define XBM_WIDTH  128
#define XBM_HEIGHT 64

// Include JPG-Array (wenn realer Modus)
#if !USE_TEST_PATTERN
    #include "frank_128x64_clean_jpg.h" // definiert das C-Array frank_128x64_clean_jpg[]
#endif

// ==================== Hardware: U8g2 SH1106 I2C ====================
U8G2_SH1106_128X64_NONAME_F_HW_I2C u8g2(U8G2_R0, /* reset=*/ U8X8_PIN_NONE);

// ==================== XBM-Puffer ====================
// 1 Bit / Pixel -> (128*64)/8 = 1024 Bytes
static uint8_t xbm_buffer[XBM_WIDTH * XBM_HEIGHT / 8];

// Set/clear Bit: bit==1 => black pixel
inline void xbm_set_pixel(int x, int y, bool black) {
    if (x < 0 || x >= XBM_WIDTH || y < 0 || y >= XBM_HEIGHT) return;
    int byteIndex = (y * XBM_WIDTH + x) >> 3; // /8
    int bitIndex  = x & 7;                    // %8
    if (black) 
        xbm_buffer[byteIndex] |= (1 << bitIndex);
    else       
        xbm_buffer[byteIndex] &= ~(1 << bitIndex);
}

// ==================== Dither-Fehlerpuffer (Floyd–Steinberg) ====================
// Wir nutzen zwei Zeilen-Puffer mit je XBM_WIDTH + 2 Rand-Elementen.
// Fehler werden als int16 gespeichert und in Integer-Arithmetik mit Skalierung 16 gehandhabt.
static int16_t error_line1[XBM_WIDTH + 2];
static int16_t error_line2[XBM_WIDTH + 2];

static void clear_error_lines() {
    memset(error_line1, 0, sizeof(error_line1));
    memset(error_line2, 0, sizeof(error_line2));
}

// ==================== Test-Muster (schnelle Validierung) ====================
static void render_test_pattern() {
    memset(xbm_buffer, 0, sizeof(xbm_buffer)); // 0 = white (keine schwarzen Pixel)
    // horizontaler Strich in der Mitte
    int y = XBM_HEIGHT / 2;
    for (int x = 0; x < XBM_WIDTH; ++x) {
        xbm_set_pixel(x, y, true);
    }
}

// ==================== TJpg_Decoder Render-Callback ====================
// Signatur für Bodmers TJpg_Decoder: void callback(uint16_t *pPixels, int x, int y, int w, int h)
void jpgRender(uint16_t *pPixels, int x, int y, int w, int h) {
    // Clip-Blöcke, die komplett außerhalb liegen
    if (y >= XBM_HEIGHT || x >= XBM_WIDTH) return;

    for (int yy = 0; yy < h; ++yy) {
        int ty = y + yy;
        if (ty < 0 || ty >= XBM_HEIGHT) continue;

        // Wähle die aktuellen Fehlerzeilen
        int16_t* cur = (ty % 2 == 0) ? error_line1 : error_line2;
        int16_t* nxt = (ty % 2 == 0) ? error_line2 : error_line1;

        // Wenn Block am Zeilenanfang startet, lösche die "next" Linie (Vorbereitung)
        if (x == 0) {
            memset(nxt, 0, sizeof(int16_t) * (XBM_WIDTH + 2));
        }

        for (int xx = 0; xx < w; ++xx) {
            int tx = x + xx;
            if (tx < 0 || tx >= XBM_WIDTH) { continue; }

            // RGB565 -> 8-bit Komponenten
            uint16_t pix = pPixels[yy * w + xx];
            uint8_t r5 = (pix >> 11) & 0x1F;
            uint8_t g6 = (pix >> 5) & 0x3F;
            uint8_t b5 = (pix >> 0) & 0x1F;
            uint8_t r8 = (r5 << 3) | (r5 >> 2);
            uint8_t g8 = (g6 << 2) | (g6 >> 4);
            uint8_t b8 = (b5 << 3) | (b5 >> 2);

            // Luminanz (0..255)
            int lum = (299 * r8 + 587 * g8 + 114 * b8) / 1000;

            // Fehler aus aktueller Zeile hinzufügen (Index mit +1 wegen Rand-Padding)
            int idx = tx + 1;
            int corrected = lum + (cur[idx] >> 4); // cur holds errors scaled by 16
            corrected = constrain(corrected, 0, 255);

            int out; // 0 = black, 255 = white (we invert later when setting bits)
            if (USE_DITHERING) {
                out = (corrected < 128) ? 0 : 255;
                int err = corrected - out; // -255..255

                // Fehler skalieren um 16 (Ganzzahlarithmetik)
                int e = err * 16;
                // right
                if (tx + 1 < XBM_WIDTH) cur[idx + 1] += (e * 7) / 16;
                // bottom-left
                if (ty + 1 < XBM_HEIGHT && tx - 1 >= 0) nxt[(tx - 1) + 1] += (e * 3) / 16;
                // bottom
                if (ty + 1 < XBM_HEIGHT) nxt[idx] += (e * 5) / 16;
                // bottom-right
                if (ty + 1 < XBM_HEIGHT && tx + 1 < XBM_WIDTH) nxt[(tx + 1) + 1] += (e * 1) / 16;
            } else {
                // simples Thresholding
                out = (corrected < 128) ? 0 : 255;
            }

            // Setze Pixel im XBM-Puffer: out==0 => black pixel => set bit 1
            bool black = (out == 0);
            xbm_set_pixel(tx, ty, black);

            // Clear current slot um Ringwrap zu verhindern
            cur[idx] = 0;
        } // for xx
    } // for yy
}
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
